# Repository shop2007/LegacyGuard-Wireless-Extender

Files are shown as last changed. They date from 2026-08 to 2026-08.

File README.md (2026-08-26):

# LegacyGuard Wireless Extender (Master to 4 Slave PIR/Sensors)

A wireless extension system to connect (via WiFi) up to 4 additional PIR sensors or N.O. contacts to a wired alarm control panel.  
Based on a **Master-Slave** architecture over a local Wi-Fi network, it allows a central board (Master) to monitor the status of up to 4 peripheral nodes (Slaves, wired locally to PIR sensors and powered locally) and activate a relay in case an alarm is detected.  
It is useful for adding PIR sensors to older-generation wired alarm systems without the need for additional cabling.

---

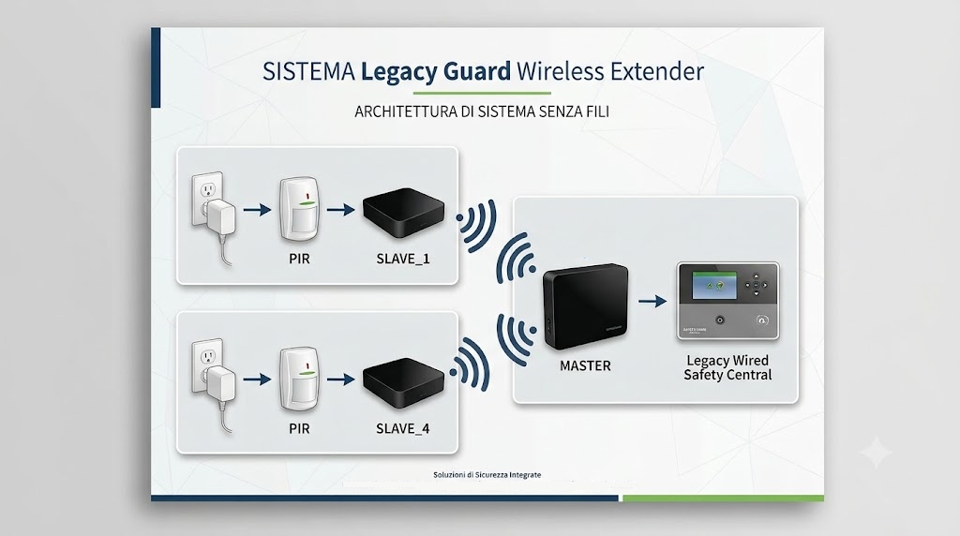
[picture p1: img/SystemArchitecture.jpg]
System Architecture
  
---

## 📐 System Architecture

```text
               +----------------------------------+
               |        MASTER (ESP32)            |
               |       IP: 192.168.4.1            |
               |   Relay Output / OLED Display    |
               +-----------------+----------------+
                                 |
         +-----------------------+-----------------------+
         | (Wi-Fi 802.11b - Network 192.168.4.x / Port 4210) |
         v                                               v
+------------------+                           +------------------+
| SLAVE 2 (ESP8266)|                           | SLAVE 3..5       |
| PIR Sensor       |  ... (up to 4 slaves) ... | (ESP8266)        |
| IP: 192.168.4.2  |                           | IP: 192.168.4.x  |
+------------------+                           +------------------+
```

link
- [master board ](https://github.com/shop2007/LegacyGuard-Wireless-Extender/tree/main/master-board)

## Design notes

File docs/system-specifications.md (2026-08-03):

# Specifiche Generali di Sistema — LegacyGuard Wireless Extender 

Questo documento descrive nel dettaglio l'architettura, le componenti, i protocolli di comunicazione e le modalità operative del sistema di allarme/ripetitore PIR Master-Slave.

---
System Architecture 
---

## 1. Architettura di Rete e Comunicazione

* **Tipologia Rete**: Wi-Fi Standard 802.11b (configurato per massimizzare la portata e la stabilità del segnale senza sleep radio).
* **Topologia**: Stella (Master al centro, Slave periferici).
* **Indirizzamento IP**:
  * **Master**: `192.168.4.1`
  * **Slave ID 2**: `192.168.4.2`
  * **Slave ID 3**: `192.168.4.3`
  * **Slave ID 4**: `192.168.4.4`
  * **Slave ID 5**: `192.168.4.5`
* **Porta del Server TCP Slave**: `80` (utilizzata dal Master per interrogare lo stato degli slave).
* **Potenza di Trasmissione TX (Slave)**: 20.5 dBm.

---

## 2. Modulo Master (`4MASTER32_displ_pir_wdog_100`)

Il nodo Master (basato su ESP32) coordina la rete, interroga periodicamente gli slave e gestisce la logica degli allarmi.

### 2.1 Logica di Allarme e Relè
* **Stati rilevati dallo Slave**:
  * `STA100`: Slave presente, nessun allarme.
  * `STA113`: Slave presente, allarme rilevato (sensore PIR attivato).
* **Comportamento Relè**: Se almeno uno slave risponde con `STA113`, l'uscita a relè viene attivata. Il relè resta eccitato per un tempo minimo di **2 secondi**, anche se la condizione di allarme rientra prima.
* **Mappatura Conservativa**: Un nodo visto anche solo una volta viene memorizzato come "Presente". Per essere dichiarato "Assente", deve fallire multiple risposte consecutive al polling.

### 2.2 Display OLED Master
La matrice del display mostra lo stato dei 4 nodi in forma sintetica:
* `A2`: Slave 2 in Allarme.
* `N3`: Slave 3 Normale / Senza allarme.
* `..`: Slave Non rilevato / Assente.

### 2.3 Indicatori LED Master
* **LED di Bordo**: Alterna stato ad ogni ciclo completo di polling (indicatore di attività).
* **LED Ausiliario (GPIO 9)**: Si illumina durante le fasi di scan e mappatura degli slave.

### 2.4 Ingressi di Servizio (Ponticelli Master)
* **GPIO 4 ➔ GND**: Salta il ritardo di riscaldamento iniziale di 90 secondi.
* **GPIO 10 ➔ GND**: Forza la rimappatura dinamica degli slave ad ogni ciclo.

### 2.5 Console Diagnostica (Seriale & Telnet)
L'accesso alla console di amministrazione avviene tramite **Seriale USB (115200 baud)** oppure via **Telnet**:
* **Accesso Telnet**: `telnet 192.168.4.1 2323`
* **Credenziali Console**: User: `admin` | Password: `Pautax2006`
* **Menu Diagnostico (Comando `m` o `M`)**:
  * `0`: Reset hardware della scheda.
  * `1`: Stampa il nome del file sorgente firmware.
  * `2`: Stampa statistiche dettagliate (allarmi, chiamate OK, chiamate FALLITE per ogni slave).
  * `3`: Abilita/Disabilita diagnostica estesa (tracing funzioni).
  * `4`: Avvia scan continuo di presenza/assenza (uscita con `q`).
  * `5`: Attiva la modalità aggiornamento OTA via Web.
  * `6`: Stampa Indirizzo MAC.
  * `99`: Uscita dal menu.

### 2.6 Aggiornamento Firmware Web OTA
1. Aprire la sessione Telnet ed entrare nel menu diagnostico (`m`).
2. Selezionare l'opzione `5` per abilitare l'OTA (il Master entra in modalità manutenzione).
3. Aprire il browser all'indirizzo `http://192.168.4.1/update` (HTTP, non HTTPS).
4. Inserire le credenziali OTA (`admin` / `Pautax2006`).
5. Caricare il file `.bin` compilato e attendere il riavvio automatico.

---

## 3. Modulo Slave PIR (`Wemos D1 mini`)

Ogni nodo Slave acquisisce il segnale dal sensore PIR e risponde alle chiamate TCP del Master.

### 3.1 Funzionalità Principali
* **Rilevamento Allarme Memorizzato (Latch)**: Quando il PIR rileva un'intrusione, il flag di allarme viene alzato e memorizzato (latched). **Importante**: il semplice polling da parte del Master NON azzera lo stato di allarme.
* **Reset Allarme via Comando `STA155`**: Lo stato di allarme memorizzato (e il relativo LED diagnostico) si azzera **esclusivamente** quando lo Slave riceve il comando specifico con codice `155` / `STA155` (inviato via TCP o Seriale).
* **Watchdog Software**: Timer a 8 secondi con auto-reset della scheda in caso di blocco del codice.
* **Risposta TCP**: Invia lo stato (`STA100` in assenza di allarme, `STA113` in presenza di allarme latched), il numero progressivo di chiamata (`CALL`) e la potenza del segnale Wi-Fi (`RADIO` / `RSSI`).

### 3.2 Display OLED Slave
* **Riga 1**: ID Slave (`SLAVE_ID`) e stato connessione Wi-Fi (`CONN` / `NOCN`).
* **Riga 2**: Stato Allarme (`OK` / `AL`).
* *Fase di avvio*: Mostra il countdown dei secondi rimanenti al riscaldamento del sensore PIR.

### 3.3 Codici e Funzionalità LED Slave
* **LED_BUILTIN** (attivo LOW):
  * **Toggle (1 “blink” di stato)**: Inverte il proprio stato ad ogni risposta trasmessa al Master (sia via TCP sia via comando seriale `?`). Serve da indicatore di attività/polling.
  * **Doppio blink (2 blink) durante riscaldamento PIR**: Nella fase di countdown di 90 s (se non saltata tramite D6→GND) esegue una sequenza fissa di **2 lampeggi rapidi** per ogni secondo di attesa:
    * ON 120 ms → OFF 120 ms → ON 120 ms → ripristino stato precedente + pausa 640 ms.
    * La sequenza è ripetuta per ogni secondo del countdown (funzione `blinkWarmupDouble()`).
  * Non sono implementati pattern a 3 o 4 blink; il LED_BUILTIN usa esclusivamente il toggle di attività e il doppio blink di warmup.
* **LED Diagnostico Allarme (`LED_DIAG_PIN` su D7)**:
  * **Si accende (HIGH)**: Non appena il PIR rileva un allarme e alza il flag interno.
  * **Rimane ACCESO**: Anche durante i normali cicli di polling/interrogazione, finché l'allarme resta memorizzato.
  * **Si spegne (LOW)**: Soltanto dopo la ricezione esplicita del comando di reset (inviata dal MASTER) `STA155`.

### 3.4 Ingressi Hardware e Interfacce Slave
* **Pin D6 (`SkipDelayPir`)**: Pull-up interno. Se ponticellato a GND all'avvio, salta il countdown di 90s del PIR (utilizzato per debug/test).
* **Pin D5 (`InputPir`)**: Ingresso del sensore PIR con pull-up interno. Supporta la configurazione con optocoppiatore/contatto normalmente chiuso (`PirReverse = false` o `true` in base alla logica del sensore).
* **Pin D7 (`LED_DIAG_PIN`)**: Uscita attiva alta collegata all'anodo del LED diagnostico allarme (con opportuna resistenza di limitazione verso GND).
* **Interfaccia Seriale USB**:
  * Inviando `?` simula una chiamata di polling fornendo la risposta di stato.
  * Inviando `155` o `STA155` forza il reset immediato dell'allarme latched e lo spegnimento del LED diagnostico.

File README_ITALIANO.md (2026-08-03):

#  LegacyGuard Wireless Extender (Master to 4 Slave PIR/Sensors)

Un sistema di estensione wireless per collegare (WiFi) ulteriori 4 sensori PIR oppure contatti n.o., ad una centrale cablata. 
Basato su architettura **Master-Slave** , tramite una rete Wi-Fi locale, consente ad una scheda centrale (Master) di monitorare lo stato di fino a 4 nodi periferici (Slave cablati localmente con sensori PIR ed alimentati localmente) e attivare un relè in caso di allarme rilevato.
E' utile per aggiungere sensori PIR a sistemi di allarme cablati di vecchia generazione, senza dover aggiungere 
cablaggi. 

---

System Architecture 
---

## 📐 Architettura del Sistema

```text
               +----------------------------------+
               |        MASTER (ESP32)            |
               |       IP: 192.168.4.1            |
               |   Uscita Relè / Display OLED     |
               +-----------------+----------------+
                                 |
         +-----------------------+-----------------------+
         | (Wi-Fi 802.11b - Rete 192.168.4.x / Port 4210) |
         v                                               v
+------------------+                           +------------------+
| SLAVE 2 (ESP8266)|                           | SLAVE 3..5       |
| Sensor PIR       |  ... (fino a 4 slave) ... | (ESP8266)        |
| IP: 192.168.4.2  |                           | IP: 192.168.4.x  |
+------------------+                           +------------------+

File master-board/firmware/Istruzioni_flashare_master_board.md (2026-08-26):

**Passi consigliati per chi parte da zero:**
**Programmazione scheda MASTER:**
Aprire il file - <https://github.com/shop2007/LegacyGuard-Wireless-Extender/tree/main/master-board%2Fdocs> ed andare al punto 8 toolchain (Riprodurre il progetto: cosa serve) 

---

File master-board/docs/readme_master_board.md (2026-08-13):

# General System Specifications — LegacyGuard Wireless Extender

This document describes in detail the architecture, components, communication protocols, and operating modes of the wireless link system for a legacy (wired) alarm control panel.

---

## 1. Network Architecture and Communication

* **Network Type**: Wi-Fi Standard 802.11b (configured to maximize range and signal stability without radio sleep).
* **Topology**: Star (Master at the center, peripheral Slaves).
* **IP Addressing**:
  * **Master**: `192.168.4.1`
  * **Slave ID 2**: `192.168.4.2`
  * **Slave ID 3**: `192.168.4.3`
  * **Slave ID 4**: `192.168.4.4`
  * **Slave ID 5**: `192.168.4.5`
* **Slave TCP Server Port**: `80` (used by the Master to query the status of the slaves).
* **TX Transmission Power (Slave)**: 20.5 dBm.

---

## 2. Master Module (`4MASTER32_displ_pir_wdog_70`)

The Master node (based on ESP32) coordinates the network, periodically queries the slaves, and manages the alarm logic.

### 2.1 Alarm Logic and Relay
* **States detected by the Slave**:
  * `STA100`: Slave present, no alarm.
  * `STA113`: Slave present, alarm detected (PIR sensor activated).
* **Relay Behavior**: If at least one slave responds with `STA113`, the relay output is activated. The relay remains energized for a minimum time of **2 seconds**, even if the alarm condition clears earlier.
* **Conservative Mapping**: A node seen even only once is memorized as "Present". To be declared "Absent", it must fail multiple consecutive responses to polling.

### 2.2 Master OLED Display
The display matrix shows the status of the 4 nodes in synthetic form:
* `A2`: Slave 2 in Alarm.
* `N3`: Slave 3 Normal / No alarm.
* `..`: Slave Not detected / Absent.

### 2.3 Master LED Indicators
* **Edge LED**: Alternates state at each complete polling cycle (activity indicator).
* **Auxiliary LED (GPIO 9)**: Lights up during slave scan and mapping phases.

### 2.4 Service Inputs (Master Jumpers)
* **GPIO 4 ➔ GND**: Skips the initial 90-second warm-up delay.
* **GPIO 10 ➔ GND**: Forces dynamic remapping of the slaves at every cycle.

### 2.5 Diagnostic Console (Serial & Telnet)
Access to the administration console is via **USB Serial (115200 baud)** or via **Telnet**:
* **Telnet Access**: `telnet 192.168.4.1 2323`
* **Console Credentials**: User: `admin` | Password: `Pautax2006`
* **Diagnostic Menu (Command `m` or `M`)**:
  * `0`: Hardware reset of the board.
  * `1`: Prints the source firmware file name.
  * `2`: Prints detailed statistics (alarms, OK calls, FAILED calls for each slave).
  * `3`: Enables/Disables extended diagnostics (function tracing).
  * `4`: Starts continuous presence/absence scan (exit with `q`).
  * `5`: Activates Web OTA update mode.
  * `6`: Prints MAC Address.
  * `99`: Exit from the menu.

### 2.6 Web OTA Firmware Update
1. Open the Telnet session and enter the diagnostic menu (`m`).
2. Select option `5` to enable OTA (the Master enters maintenance mode).
3. Open the browser at the address `http://192.168.4.1/update` (HTTP, not HTTPS).
4. Enter the OTA credentials (`admin` / `Pautax2006`).
5. Upload the compiled `.bin` file and wait for the automatic reboot.
p.s. more details on programming and OTA are available in paragraph 8. (Reproducing the project: what is needed)

---

## 3. Slave PIR Module (`ESP8266 / Wemos D1 mini`)

Each Slave node acquires the signal from the PIR sensor and responds to TCP calls from the Master.

### 3.1 Main Functionalities
* **Latched Alarm Detection**: When the PIR detects an intrusion, the alarm flag is raised and latched. **Important**: simple polling by the Master does NOT clear the alarm state.
* **Alarm Reset via Command `STA155`**: The latched alarm state (and the related diagnostic LED) is cleared **exclusively** when the Slave receives the specific command with code `155` / `STA155` (sent via TCP or Serial).
* **Software Watchdog**: 8-second timer with automatic board reset in case of code freeze.
* **TCP Response**: Sends the status (`STA100` in the absence of alarm, `STA113` in the presence of latched alarm), the progressive call number (`CALL`), and the Wi-Fi signal strength (`RADIO` / `RSSI`).

### 3.2 Slave OLED Display
* **Line 1**: Slave ID (`SLAVE_ID`) and Wi-Fi connection status (`CONN` / `NOCN`).
* **Line 2**: Alarm status (`OK` / `AL`).
* *Startup phase*: Shows the countdown of remaining seconds for PIR sensor warm-up.

### 3.3 Slave LED Codes and Functionalities
* **LED_BUILTIN** (active LOW):
  * **Toggle (1 “status blink”)**: Inverts its state at every response transmitted to the Master (both via TCP and via serial command `?`). Serves as an activity/polling indicator.
  * **Double blink (2 blinks) during PIR warm-up**: In the 90 s countdown phase (if not skipped via D6→GND) it performs a fixed sequence of **2 rapid flashes** for each second of waiting:
    * ON 120 ms → OFF 120 ms → ON 120 ms → restore previous state + 640 ms pause.
    * The sequence is repeated for each second of the countdown (function `blinkWarmupDouble()`).
  * Patterns with 3 or 4 blinks are not implemented; the LED_BUILTIN uses exclusively the activity toggle and the warm-up double blink.
* **Alarm Diagnostic LED (`LED_DIAG_PIN` on D7)**:
  * **Turns on (HIGH)**: As soon as the PIR detects an alarm and raises the internal flag.
  * **Remains ON**: Even during normal polling/interrogation cycles, as long as the alarm remains latched.
  * **Turns off (LOW)**: Only after explicit reception of the reset command (sent by the MASTER) `STA155`.

### 3.4 Slave Hardware Inputs and Interfaces
* **Pin D6 (`SkipDelayPir`)**: Internal pull-up. If jumpered to GND at startup, skips the 90 s PIR countdown (used for debug/test).
* **Pin D5 (`InputPir`)**: PIR sensor input with internal pull-up. Supports configuration with optocoupler/normally closed contact (`PirReverse = false` or `true` depending on the sensor logic).
* **Pin D7 (`LED_DIAG_PIN`)**: Active-high output connected to the anode of the alarm diagnostic LED (with appropriate current-limiting resistor to GND).
* **USB Serial Interface**:
  * Sending `?` simulates a polling call providing the status response.
  * Sending `155` or `STA155` forces the immediate reset of the latched alarm and turns off the diagnostic LED.

# LegacyGuard Wireless Extender

**Network Master board for monitoring 4 slave boards connected to PIR-type sensors, Dual technology, normally closed magnetic switches.**

The **master** board, based on **ESP32-C3**, manages a proprietary local WiFi network (Access Point) consisting of one master and up to **4 remote slaves** (expandable to 8 with firmware modification). The master periodically queries the slaves, acquires their operational status (presence / alarm), and drives a relay output in case of alarm. The status of the 4 slaves is shown in real time on an OLED display.

> This document describes the hardware, protocol, firmware, and the procedure to reproduce or modify the project.

---

## 1. Overview

| | |
|---|---|
| **MCU** | ESP32-C3 (API core: `WiFi.h`, `WebServer.h`, `esp_task_wdt.h`, `Update.h`) |
| **Role** | Network Master: polling of up to 4 slaves, alarm management, display, OTA |
| **Network** | Own WiFi Access Point (no need for the WiFi router to be on) |
| **Output** | Alarm relay, OLED display, 2 status LEDs |
| **Update** | OTA via web interface, protected by authentication |
| **Diagnostics** | Serial console (115200 baud) or Telnet, with command menu |

---

## 2. Network Architecture

- The master creates its own **WiFi Access Point** (SoftAP), to which slaves and the diagnostic station connect.
- Internally managed network on a static range (fixed master IP: `192.168.4.1`).
- Each slave has an ID (`SLAVE_ID`) ranging, according to the project numbering, from 2 to 5 (the master has fixed ID 1, so that master and slaves do not collide on the same network).
- Each slave, when queried, transmits to the master a synthetic status derived from an internal code:
  - status (display) **A** (alarm) ↔ real code `STA113`
  - status (display) **N** (normal) ↔ real code `STA100`
  - status (display) **..** ↔ slave absent / not detected

---

## 3. Master Operating Logic

- The master cyclically queries (polls) all configured slaves.
- **If at least one slave is in alarm**, the output relay is activated.
- **Minimum hysteresis**: once activated, the relay remains active for **at least 2 seconds**, even if the alarm clears earlier.
- **Slave presence detection (conservative mapping)**, designed for non-optimal radio networks (distance, weak signal):
  - in the mapping phase, a slave seen even only once is considered present;
  - in normal polling, a slave is declared absent only after **multiple consecutive missed responses** (not on the first one).

---

## 4. User Interface on the Board

### 4.1 OLED Display
Shows the status of the 4 slaves in compact form, two characters per slave:

| Code | Meaning |
|---|---|
| `A2` | slave 2 in alarm |
| `N3` | slave 3 present, no alarm |
| `..` | slave not present / not detected |

### 4.2 LEDs
- **Edge LED (built-in)**: normal master operation, changes state at every complete polling cycle (useful to verify "at a glance" that the firmware is not frozen).
- **Auxiliary LED (GPIO 9)**: on during slave mapping/scan, off at the end of the operation.

### 4.3 Service Jumpers (jumper to GND)
| ESP32-C3 CHIP Pin | Function |
|---|---|
| GPIO 4 → GND | skips the initial startup delay (90 s) |
| GPIO 10 → GND | forces complete remapping of the slaves at every cycle, for debug only |

---

## 5. Diagnostic Access

The master exposes a diagnostic console reachable in two ways:

- **USB Serial**, 115200 baud
- **Telnet**, on the master's WiFi network, default port `2323`

Typical connection command to launch from console (CMD window):
```
telnet 192.168.4.1 2323
```

Access requires console username/password. To open the diagnostic menu, from the session (serial or Telnet) send the character **`m`**.

### Diagnostic Menu — Available Commands

| Command | Function |
|---|---|
| `0` | Hardware reset of the board |
| `1` | Displays the source file name of the running firmware |
| `2` | Statistics per slave: number of alarms, OK readings, failed readings (`ALRM`, `OK`, `NON_OK`) useful for evaluating the quality of the WiFi connection over the long term |
| `3` | Enables/disables extended diagnostics (detailed function entry/exit tracing for the developer) |
| `4` | Continuous scan of present/absent slaves (ends with `q`) |
| `5` | Enables/disables web OTA mode |
| `6` | Prints the board MAC address |
| `99` | Exits the menu |

Example output of command `2`: (n. alarms, presence readings on network ok, presence readings on network failed)
```
Slave2 ALRM=3 OK=6403 NON_OK=2
Slave3 ALRM=0 OK=0    NON_OK=6405
Slave4 ALRM=0 OK=0    NON_OK=6405
Slave5 ALRM=0 OK=0    NON_OK=6405
```

---

## 6. Firmware Update via OTA

The firmware includes an OTA web server (`WebServer` + `Update.h` library) always available on the master's IP, protected by HTTP Basic authentication.

**Complete procedure:**
1. Download the updated (`.bin`) file.
2. Save it in a known folder.
3. Disconnect the PC from the router network and connect it to the WiFi network `88888888` pass `88888888`.
4. Open a Telnet session to `192.168.4.1:2323`. (From CMD prompt write "telnet 192.168.4.1 2323")
5. Authenticate with user 'admin' and password Pautax2006.
6. Send `m` to open the diagnostic menu.
7. Send `5` to activate OTA mode.   ??????? verify procedure
8. Open in the browser `http://192.168.4.1/update` (**http**, not https).
9. Enter the OTA credentials (username admin, password Pautax2006).
10. On the web page with browse, search on disk for the `.bin` file.
11. Wait for the upload to complete.
12. Wait for the automatic reboot of the board.
13. Verify the correct operation of the new firmware.

During OTA the master enters **maintenance mode** (polling/normal functions are suspended).

---

## 7. Firmware Structure and Project Files

```
4MASTER32/
├── 4MASTER32_startup_03_88888888.ino      # first boot / recovery sketch (OTA + serial)
├── 4MASTER32_displ_pir_wdog_100.ino.bin   # actual firmware  
```

### 7.1 First Boot Sketch (`4MASTER32_startup_02_88888888.ino`)
The *startup* sketch is a **minimal first boot / recovery variant**: it only mounts the WiFi Access Point, the OTA web server, and the hardware watchdog, periodically printing on the serial a message inviting to update the firmware. **It does not contain** the slave polling logic, display, and relay described in the manual: it is designed to easily flash a "virgin" board (or recover a locked board) and bring it via OTA to the complete application firmware, without having to reconnect it via USB.

Main technical elements:
- Hardware task watchdog (`esp_task_wdt`), 8 s timeout, with `trigger_panic` active — if the loop freezes, the board resets itself.
- OTA web server (`WebServer` on port 80) with HTTP Basic authentication.
- `/update` endpoint for binary upload, handled in streaming (`UPLOAD_FILE_START` / `WRITE` / `END` / `ABORTED`) with progress log on serial.
- Automatic reboot (`ESP.restart()`) 1.5 s after OTA completion.

### 7.2 `Master_ID.h`
Defines the master's identity on the network and the network/console parameters:
- `MASTER_ID` — fixed at `1` (slaves use 2–9, max 8 slaves on the network).
- SSID / password of the master's Access Point.
- Static IP, gateway, subnet of the AP.
- Application TCP port, Telnet diagnostic console port and password.
- OTA web server port, user, and password.
- `NUM_SLAVES`, `FIRST_SLAVE_ID` — number and first ID of the expected slaves on the network.
- An empirical reminder on radio signal level measurements (e.g. at 30 cm about −33 dB, at 7 m about −85/−92 dB), useful to understand the AP range limits during system design.

PLEASE NOTE: this file is not accessible, but contained in the .bin file.

### 7.3 `Choice of WiFi SSID and PASSWORD Parameters`
- The desired local network name (SSID) and WiFi password must be requested at the address register@realmeteo.com, together with the MAC Address of the ESP32-C3 board, readable from the service menu with command 6.
- These parameters (SSID and PASSWORD) must be reported identically in the Slave_ID.h file before programming the SLAVE modules (WEMOS LOLIN D1), by editing these two lines
- const char* WIFI_SSID = "DESIRED-WIFI-NETWORK-NAME";
- const char* WIFI_PASS = "WIFI-PASSWORD";

### 7.4 `Technical Note: partitions.csv`
ESP32-c3 flash partitioning table, **OTA dual-app** scheme (necessary for safe OTA updates, with rollback):

| Name | Type | Sub-type | Offset | Size |
|---|---|---|---|---|
| `nvs` | data | nvs | `0x9000` | 20 KB |
| `otadata` | data | ota | `0xe000` | 8 KB |
| `app0` | app | ota_0 | `0x10000` | 1900 KB |
| `app1` | app | ota_1 | — | 1900 KB |
| `coredump` | data | coredump | — | 128 KB |

Two application slots (`app0`/`app1`) of 1900 KB each allow the OTA to write the new firmware to the inactive slot and switch to it only after a successful upload, maintaining the possibility of returning to the previous firmware in case of problems. The `coredump` partition stores a dump in case of crash to facilitate debugging.

---

## 8. Reproducing the Project: What is Needed

**Hardware:**
- ESP32‐C3 board with 0.42-inch OLED display WiFi Bluetooth
- PCB
- Relay
- PIR sensors and dedicated D1 slave boards (one for each point to monitor)
- 2 LEDs (edge + auxiliary on GPIO 9)
- 2 jumpers/buttons to GND on GPIO 4 and GPIO 10

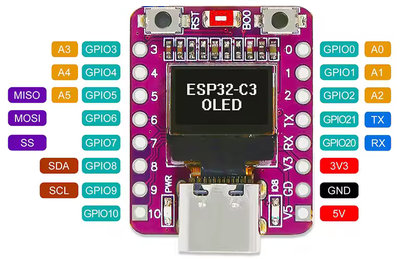
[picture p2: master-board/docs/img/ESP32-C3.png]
ESP32-C3


**Toolchain:**
- Arduino IDE with ESP32 core installed and setting of the file "http://arduino.esp8266.com/stable/package_esp8266com_index.json" in preferences
- Libraries: `WiFi.h`, `WebServer.h`, `Update.h`, `esp_task_wdt.h` (included in the ESP32 core, no additional installation required)

**MASTER Board Programming:**
0. Download all the files present in the firmware folder, copying them to a known folder on your PC.
0.1 Optional but preferable: Remove the ESP32-C3 board from the board and connect it to the PC via the USB cable
1. In Arduino IDE2, set the following:
1.1 File->Preferences-> Additional board manager url-> http://arduino.esp8266.com/stable/package_esp8266com_index.json
1.2 Board "ESP32‐C3 Dev Module"
1.3 Tools-> Erase all flash before upload ->Enabled
1.4 Tools-> USB CDC on boot -> Enabled
2. Open the sketch "4MASTER32_startup_02_88888888.ino" and upload it to an ESP32C3 board (preferably with 0.42-inch OLED display).
2.1 Verify from the serial terminal at 115200 baud the following message:  =========================================
SoftAP started - SSID: 88888888
IP for OTA update: http://192.168.4.1
=========================================
perform OTA update

3. Verify with the PC that among the other WiFi networks there is also the network with SSID = **88888888** (it reads INTERNET NOT AVAILABLE).
4. Disconnect the PC from your router's WiFi network and connect to the network with SSID 88888888 using password 88888888
5. In the PC browser type the following address (optionally leave the serial monitor active) http://192.168.4.1/update   (attention, not https)
5.1 You will be asked to authenticate: user 'admin' password 'Pautax2006'
6. With browse search for the file 4MASTER32_displ_pir_wdog_100.bin (N.B. 100 is the version, you might also find an upgrade with another number).
6.1 Program the board with the 'Upload Firmware' button
6.2 on the serial terminal you read:
OTA: Firmware upload started.
OTA: File = 4MASTER32_displ_pir_wdog_100.ino.bin
OTA: Upload completed. Bytes received: 1072240
OTA: update completed. Restarting...
perform OTA update
Device restart in progress...
6.3 on the browser you read: **Update completed. The master is restarting.**

---

## 9. PCB

- The PCBs for mounting MASTER and SLAVE boards are under development and will be distributed at `cost price`, if you are interested book them.

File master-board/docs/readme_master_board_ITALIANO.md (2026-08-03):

# Specifiche Generali di Sistema — LegacyGuard Wireless Extender 

Questo documento descrive nel dettaglio l'architettura, le componenti, i protocolli di comunicazione e le modalità operative del sistema di collegamento wireless per una centrale antifurto legacy (wired)

---

## 1. Architettura di Rete e Comunicazione[cite: 2]

* **Tipologia Rete**: Wi-Fi Standard 802.11b (configurato per massimizzare la portata e la stabilità del segnale senza sleep radio).[cite: 2]
* **Topologia**: Stella (Master al centro, Slave periferici).[cite: 2]
* **Indirizzamento IP**:[cite: 2]
  * **Master**: `192.168.4.1`[cite: 2]
  * **Slave ID 2**: `192.168.4.2`[cite: 2]
  * **Slave ID 3**: `192.168.4.3`[cite: 2]
  * **Slave ID 4**: `192.168.4.4`[cite: 2]
  * **Slave ID 5**: `192.168.4.5`[cite: 2]
* **Porta del Server TCP Slave**: `80` (utilizzata dal Master per interrogare lo stato degli slave).[cite: 1, 2]
* **Potenza di Trasmissione TX (Slave)**: 20.5 dBm.[cite: 2]

---

## 2. Modulo Master (`4MASTER32_displ_pir_wdog_70`)[cite: 2]

Il nodo Master (basato su ESP32) coordina la rete, interroga periodicamente gli slave e gestisce la logica degli allarmi.[cite: 2]

### 2.1 Logica di Allarme e Relè[cite: 2]
* **Stati rilevati dallo Slave**:[cite: 2]
  * `STA100`: Slave presente, nessun allarme.[cite: 2]
  * `STA113`: Slave presente, allarme rilevato (sensore PIR attivato).[cite: 2]
* **Comportamento Relè**: Se almeno uno slave risponde con `STA113`, l'uscita a relè viene attivata. Il relè resta eccitato per un tempo minimo di **2 secondi**, anche se la condizione di allarme rientra prima.[cite: 2]
* **Mappatura Conservativa**: Un nodo visto anche solo una volta viene memorizzato come "Presente". Per essere dichiarato "Assente", deve fallire multiple risposte consecutive al polling.[cite: 2]

### 2.2 Display OLED Master[cite: 2]
La matrice del display mostra lo stato dei 4 nodi in forma sintetica:[cite: 2]
* `A2`: Slave 2 in Allarme.[cite: 2]
* `N3`: Slave 3 Normale / Senza allarme.[cite: 2]
* `..`: Slave Non rilevato / Assente.[cite: 2]

### 2.3 Indicatori LED Master[cite: 2]
* **LED di Bordo**: Alterna stato ad ogni ciclo completo di polling (indicatore di attività).[cite: 2]
* **LED Ausiliario (GPIO 9)**: Si illumina durante le fasi di scan e mappatura degli slave.[cite: 2]

### 2.4 Ingressi di Servizio (Ponticelli Master)[cite: 2]
* **GPIO 4 ➔ GND**: Salta il ritardo di riscaldamento iniziale di 90 secondi.[cite: 2]
* **GPIO 10 ➔ GND**: Forza la rimappatura dinamica degli slave ad ogni ciclo.[cite: 2]

### 2.5 Console Diagnostica (Seriale & Telnet)[cite: 2]
L'accesso alla console di amministrazione avviene tramite **Seriale USB (115200 baud)** oppure via **Telnet**:[cite: 2]
* **Accesso Telnet**: `telnet 192.168.4.1 2323`[cite: 2]
* **Credenziali Console**: User: `admin` | Password: `Pautax2006`[cite: 2]
* **Menu Diagnostico (Comando `m` o `M`)**:[cite: 2]
  * `0`: Reset hardware della scheda.[cite: 2]
  * `1`: Stampa il nome del file sorgente firmware.[cite: 2]
  * `2`: Stampa statistiche dettagliate (allarmi, chiamate OK, chiamate FALLITE per ogni slave).[cite: 2]
  * `3`: Abilita/Disabilita diagnostica estesa (tracing funzioni).[cite: 2]
  * `4`: Avvia scan continuo di presenza/assenza (uscita con `q`).[cite: 2]
  * `5`: Attiva la modalità aggiornamento OTA via Web.[cite: 2]
  * `6`: Stampa Indirizzo MAC.[cite: 2]
  * `99`: Uscita dal menu.[cite: 2]

### 2.6 Aggiornamento Firmware Web OTA[cite: 2]
1. Aprire la sessione Telnet ed entrare nel menu diagnostico (`m`).[cite: 2]
2. Selezionare l'opzione `5` per abilitare l'OTA (il Master entra in modalità manutenzione).[cite: 2]
3. Aprire il browser all'indirizzo `http://192.168.4.1/update` (HTTP, non HTTPS).[cite: 2]
4. Inserire le credenziali OTA (`admin` / `Pautax2006`).[cite: 2]
5. Caricare il file `.bin` compilato e attendere il riavvio automatico.[cite: 2]
p.s. maggiori dettagli sulla programmazione e OTA sono disponibili al paragrafo 8. (Riprodurre il progetto: cosa serve)
---

## 3. Modulo Slave PIR (`ESP8266 / Wemos D1 mini`)[cite: 1, 2]

Ogni nodo Slave acquisisce il segnale dal sensore PIR e risponde alle chiamate TCP del Master.[cite: 2]

### 3.1 Funzionalità Principali[cite: 2]
* **Rilevamento Allarme Memorizzato (Latch)**: Quando il PIR rileva un'intrusione, il flag di allarme viene alzato e memorizzato (latched)[cite: 1]. **Importante**: il semplice polling da parte del Master NON azzera lo stato di allarme[cite: 1].
* **Reset Allarme via Comando `STA155`**: Lo stato di allarme memorizzato (e il relativo LED diagnostico) si azzera **esclusivamente** quando lo Slave riceve il comando specifico con codice `155` / `STA155` (inviato via TCP o Seriale)[cite: 1].
* **Watchdog Software**: Timer a 8 secondi con auto-reset della scheda in caso di blocco del codice[cite: 2].
* **Risposta TCP**: Invia lo stato (`STA100` in assenza di allarme, `STA113` in presenza di allarme latched), il numero progressivo di chiamata (`CALL`) e la potenza del segnale Wi-Fi (`RADIO` / `RSSI`)[cite: 1, 2].

### 3.2 Display OLED Slave[cite: 2]
* **Riga 1**: ID Slave (`SLAVE_ID`) e stato connessione Wi-Fi (`CONN` / `NOCN`)[cite: 2].
* **Riga 2**: Stato Allarme (`OK` / `AL`)[cite: 2].
* *Fase di avvio*: Mostra il countdown dei secondi rimanenti al riscaldamento del sensore PIR[cite: 2].

### 3.3 Codici e Funzionalità LED Slave[cite: 1, 2]
* **LED_BUILTIN** (attivo LOW):
  * **Toggle (1 “blink” di stato)**: Inverte il proprio stato ad ogni risposta trasmessa al Master (sia via TCP sia via comando seriale `?`). Serve da indicatore di attività/polling.
  * **Doppio blink (2 blink) durante riscaldamento PIR**: Nella fase di countdown di 90 s (se non saltata tramite D6→GND) esegue una sequenza fissa di **2 lampeggi rapidi** per ogni secondo di attesa:
    * ON 120 ms → OFF 120 ms → ON 120 ms → ripristino stato precedente + pausa 640 ms.
    * La sequenza è ripetuta per ogni secondo del countdown (funzione `blinkWarmupDouble()`).
  * Non sono implementati pattern a 3 o 4 blink; il LED_BUILTIN usa esclusivamente il toggle di attività e il doppio blink di warmup.
* **LED Diagnostico Allarme (`LED_DIAG_PIN` su D7)**:
  * **Si accende (HIGH)**: Non appena il PIR rileva un allarme e alza il flag interno[cite: 1].
  * **Rimane ACCESO**: Anche durante i normali cicli di polling/interrogazione, finché l'allarme resta memorizzato[cite: 1].
  * **Si spegne (LOW)**: Soltanto dopo la ricezione esplicita del comando di reset (inviata dal MASTER) `STA155`[cite: 1].

### 3.4 Ingressi Hardware e Interfacce Slave[cite: 1, 2]
* **Pin D6 (`SkipDelayPir`)**: Pull-up interno. Se ponticellato a GND all'avvio, salta il countdown di 90s del PIR (utilizzato per debug/test)[cite: 1, 2].
* **Pin D5 (`InputPir`)**: Ingresso del sensore PIR con pull-up interno. Supporta la configurazione con optocoppiatore/contatto normalmente chiuso (`PirReverse = false` o `true` in base alla logica del sensore)[cite: 1, 2].
* **Pin D7 (`LED_DIAG_PIN`)**: Uscita attiva alta collegata all'anodo del LED diagnostico allarme (con opportuna resistenza di limitazione verso GND)[cite: 1].
* **Interfaccia Seriale USB**:
  * Inviando `?` simula una chiamata di polling fornendo la risposta di stato[cite: 1].
  * Inviando `155` o `STA155` forza il reset immediato dell'allarme latched e lo spegnimento del LED diagnostico[cite: 1].# LegacyGuard Wireless Extender 

** Scheda Master di rete per monitoraggio 4 schede slave connesse a sensori tipo PIR, Doppia tecnologia, interruttori magnetici normalmente chiusi.**

La scheda **master**, basata su **ESP32-C3**, gestisce una rete locale WiFi proprietaria (Access Point) composta da un master e fino a **4 slave remoti** (espandibile a 8 con modifica firmware). Il master interroga periodicamente gli slave, ne acquisisce lo stato operativo (presenza / allarme) e pilota un'uscita a relè in caso di allarme. Lo stato dei 4 slave viene mostrato in tempo reale su un display OLED.

> Questo documento descrive l'hardware, il protocollo, il firmware e la procedura per riprodurre o modificare il progetto. 

---

## 1. Panoramica

| | |
|---|---|
| **MCU** | ESP32-C3 (API core: `WiFi.h`, `WebServer.h`, `esp_task_wdt.h`, `Update.h`) |
| **Ruolo** | Master di rete: polling di fino a 4 slave, gestione allarme, display, OTA |
| **Rete** | Access Point WiFi proprio (non serve avere il router WiFi acceso) |
| **Output** | Relè di allarme, display OLED, 2 LED di stato |
| **Aggiornamento** | OTA via interfaccia web, protetta da autenticazione |
| **Diagnostica** | Console seriale (115200 baud) o Telnet, con menu a comandi |

---

## 2. Architettura di rete

- Il master crea un proprio **Access Point WiFi** (SoftAP), a cui slave e postazione di diagnostica si collegano.
- Rete gestita internamente su un range statico (IP master fisso: `192.168.4.1`).
- Ogni slave ha un ID (`SLAVE_ID`) compreso, secondo la numerazione del progetto, tra 2 e 5 (il master ha ID 1, fisso, così master e slave non collidono sulla stessa rete).
- Ogni slave, quando interrogato, trasmette al master uno stato sintetico ricavato da un codice interno:
  - stato (display) **A** (allarme) ↔ codice reale `STA113`
  - stato (display) **N** (normale) ↔ codice reale `STA100`
  - stato (display) **..** ↔ slave assente / non rilevato

---

## 3. Logica di funzionamento del master

- Il master interroga (poll) ciclicamente tutti gli slave configurati.
- **Se almeno uno slave risulta in allarme**, il relè di uscita si attiva.
- **Isteresi minima**: una volta attivato, il relè resta attivo per **almeno 2 secondi**, anche se l'allarme rientra prima.
- **Rilevamento presenza slave (mappatura conservativa)**, pensato per reti radio non ottimali (distanza, segnale debole):
  - in fase di mappatura, uno slave visto anche una sola volta viene considerato presente;
  - in polling normale, uno slave viene dichiarato assente solo dopo **più mancate risposte consecutive** (non alla prima).

---

## 4. Interfaccia utente sulla scheda

### 4.1 Display OLED
Mostra in forma compatta lo stato dei 4 slave, due caratteri per slave:

| Codice | Significato |
|---|---|
| `A2` | slave 2 in allarme |
| `N3` | slave 3 presente, nessun allarme |
| `..` | slave non presente / non rilevato |

### 4.2 LED
- **LED di bordo (built-in)**: normale funzionamento del master, cambia stato a ogni ciclo completo di polling (utile per verificare "a colpo d'occhio" che il firmware non sia bloccato).
- **LED ausiliario (GPIO 9)**: acceso durante la mappatura/scan degli slave, spento a fine operazione.

### 4.3 Ponticelli di servizio (jumper verso GND)
| Pin  CHIP ESP32 C3  | Funzione |
|---|---|
| GPIO 4 → GND | salta il ritardo iniziale di avvio (90 s) |
| GPIO 10 → GND | forza la rimappatura completa degli slave a ogni ciclo, solo per debug |

---

## 5. Accesso diagnostico

Il master espone una console diagnostica raggiungibile in due modi:

- **Seriale USB**, 115200 baud
- **Telnet**, sulla rete WiFi del master, porta di default `2323`

Comando di connessione tipico da lanciare da console (finestra CMD):
```
telnet 192.168.4.1 2323
```

L'accesso richiede username/password di console. Per aprire il menu diagnostico, dalla sessione (seriale o Telnet) inviare il carattere **`m`** .

### Menu diagnostico — comandi disponibili

| Comando | Funzione |
|---|---|
| `0` | Reset hardware della scheda |
| `1` | Visualizza nome file sorgente del firmware in esecuzione |
| `2` | Statistiche per slave: n° allarmi, letture OK, letture fallite (`ALRM`, `OK`, `NON_OK`) utile per valutare la bontà della connessione WiFi a lungo termine |
| `3` | Abilita/disabilita diagnostica estesa (tracing dettagliato ingresso/uscita funzioni per lo sviluppatore) |
| `4` | Scan continuo slave presenti/assenti (termina con `q`) |
| `5` | Abilita/disabilita modalità OTA via web |
| `6` | Stampa MAC address della scheda |
| `99` | Esce dal menu |

Esempio di output del comando `2`: (n. allarmi, letture presenza in rete ok, letture presenza in rete fallite)
```
Slave2 ALRM=3 OK=6403 NON_OK=2
Slave3 ALRM=0 OK=0    NON_OK=6405
Slave4 ALRM=0 OK=0    NON_OK=6405
Slave5 ALRM=0 OK=0    NON_OK=6405
```

---

## 6. Aggiornamento firmware via OTA

Il firmware include un web server OTA (`WebServer` + libreria `Update.h`) sempre disponibile sull'IP del master, protetto da autenticazione HTTP Basic.

**Procedura completa:**
1. Scaricare il file (`.bin`) aggiornato .
2. Salvarlo in una cartella nota .
3. Scollegare il PC dalla rete del router e collegarlo alla rete WiFi `88888888` pass `88888888`` .
4. Aprire una sessione Telnet verso `192.168.4.1:2323`.  (Da prompt CMD scrivere "telnet 192.168.4.1 2323")
5. Autenticarsi con user 'admin' e password Pautax2006.
6. Inviare `m` per aprire il menu diagnostico.
7. Inviare `5` per attivare la modalità OTA.   ??????? verificare procedura
8. Aprire nel browser `http://192.168.4.1/update` (**http**, non https).
9. Inserire le credenziali OTA (username admin, password Pautax2006).
10. Sulla pagina web con sfoglia, cercare su disco il file `.bin`.
11. Attendere il completamento dell'upload.
12. Attendere il riavvio automatico della scheda.
13. Verificare il corretto funzionamento del nuovo firmware.

Durante l'OTA il master entra in **modalità manutenzione** (il polling/le funzioni normali sono sospese).

---

## 7. Struttura firmware e file di progetto

```
4MASTER32/
├── 4MASTER32_startup_03_88888888.ino      # sketch di primo avvio / recovery (OTA + seriale)
├── 4MASTER32_displ_pir_wdog_100.ino.bin   # firmware vero e proprio  
```

### 7.1 Sketch di primo avvio (`4MASTER32_startup_02_88888888.ino`)
Lo sketch *startup* è una **variante minimale di primo avvio / recovery**: monta solo l'Access Point WiFi, il web server OTA e il watchdog hardware, stampando periodicamente sulla seriale un messaggio di invito ad aggiornare il firmware. **Non contiene** la logica di polling degli slave, display e relè descritta nel manuale: è pensato per flashare facilmenete una scheda "vergine" (o recuperare una scheda bloccata) e portarla via OTA al firmware applicativo completo, senza dover ricollegarla via USB.

Elementi tecnici principali:
- Watchdog hardware task (`esp_task_wdt`), timeout 8 s, con `trigger_panic` attivo — se il loop si blocca, la scheda si resetta da sola.
- Web server OTA (`WebServer` su porta 80) con autenticazione HTTP Basic.
- Endpoint `/update` per upload del binario, gestito in streaming (`UPLOAD_FILE_START` / `WRITE` / `END` / `ABORTED`) con log di avanzamento su seriale.
- Riavvio automatico (`ESP.restart()`) 1,5 s dopo il completamento dell'OTA.

### 7.2 `Master_ID.h`
Definisce l'identità del master sulla rete e i parametri di rete/console:
- `MASTER_ID` — fisso a `1` (gli slave usano 2–9, max 8 slave in rete).
- SSID / password dell'Access Point del master.
- IP statico, gateway, subnet dell'AP.
- Porta TCP applicativa, porta e password della console Telnet diagnostica.
- Porta, utente e password del web server OTA.
- `NUM_SLAVES`, `FIRST_SLAVE_ID` — numero e primo ID degli slave attesi in rete.
- Un promemoria empirico sulle misure di livello del segnale radio (es. a 30 cm circa −33 dB, a 7 m circa −85/−92 dB), utile per capire i limiti della portata dell'AP in fase di progettazione dell'impianto.

NOTA BENE: questo file non è accessibile, ma contenuto nel file .bin .

### 7.3 `Scelta dei parametri SSID e PASSWORD WiFi`
- Il nome della rete locale (SSID) e della password WiFi desiderate devono essere richieste all'indirizzo register@realmeteo.com , unitamente al MAC Address della scheda ESP32-C3, leggibile dal menù di servizio con il comando 6.
- Questi parametri (SSID e PASSWORD) dovranno essere riportati identici sul file Slave_ID.h prima di programmare i moduli SLAVE (WEMOS LIOLIN D1), editando queste due linee
- const char* WIFI_SSID = "NOME-DESIDERATO-RETE-WIFI";
- const char* WIFI_PASS = "PASSWORD-WIFI";

### 7.4 `Nota tecnica: partitions.csv`
Tabella di partizionamento flash ESP32-c3, schema **OTA dual-app** (necessario per gli aggiornamenti OTA sicuri, con rollback):

| Nome | Tipo | Sub-tipo | Offset | Dimensione |
|---|---|---|---|---|
| `nvs` | data | nvs | `0x9000` | 20 KB |
| `otadata` | data | ota | `0xe000` | 8 KB |
| `app0` | app | ota_0 | `0x10000` | 1900 KB |
| `app1` | app | ota_1 | — | 1900 KB |
| `coredump` | data | coredump | — | 128 KB |

Due slot applicativi (`app0`/`app1`) da 1900 KB ciascuno permettono all'OTA di scrivere il nuovo firmware nello slot inattivo e passare a quello solo dopo un upload riuscito, mantenendo la possibilità di tornare al firmware precedente in caso di problemi. La partizione `coredump` conserva un dump in caso di crash per facilitare il debug.

---

## 8. Riprodurre il progetto: cosa serve

**Hardware:**
- Scheda ESP32‐C3 con display OLED da 0,42 pollici WiFi Bluetooth
- PCB
-Relè
- Sensori PIR e schede slave D1 dedicate (una per ogni punto da monitorare)
- 2 LED (bordo + ausiliario su GPIO 9)
- 2 ponticelli/pulsanti verso GND su GPIO 4 e GPIO 10

ESP32-C3 

**Toolchain:**
- Arduino IDE con core ESP32 installato ed impostazione del file "http://arduino.esp8266.com/stable/package_esp8266com_index.json" nelle preferenze
- Librerie: `WiFi.h`, `WebServer.h`, `Update.h`, `esp_task_wdt.h` (incluse nel core ESP32, nessuna installazione aggiuntiva richiesta)

**Programmazione scheda MASTER:**
0. Scaricare tutti i files presenti nella cartella firmware, copiandoli in una cartella nota sul nostro pc.
0.1 Opzionale ma preferibile: Smontare la scheda ESP32 C3 dalla board e connetterla al pc tramite il cavetto USB
1. Su Arduino IDE2 , impostare quanto segue: 
1.1 File->Preferences-> Additional board manager url-> http://arduino.esp8266.com/stable/package_esp8266com_index.jsonze 
1.2 Board "ESP32‐C3 Dev Module"
1.3 Tools-> Erase all flash before upload ->Enabled
1.4 Tools-> USB CDC on boot -> Enabled 
2. Aprire lo sketch "4MASTER32_startup_02_88888888.ino" e caricarlo su una scheda ESP32C3 (meglio se con display OLED da 0,42 pollici).
2.1 Verificare da terminale seriale a 115200 baud il seguente messaggio:  =========================================
SoftAP avviato - SSID: 88888888
IP per aggiornamento OTA: http://192.168.4.1
=========================================
eseguire aggiornamento OTA

3. Verificare con il PC che tra le altre reti WiFi ci sia anche la rete con SSID = **88888888** (si legge INTERNET NON DISPONIBILE). 
4. Scollegare il PC dalla rete wifi del vostro router e collegare la rete con SSID 88888888 usando password 88888888
5. Sul browser del pc digitare il seguente indirizzo (opzionalmente lasciare il monitor seriale attivo) http://192.168.4.1/update   (attenzione, non https) 
5.1 Verrà richiesto di autenticarsi: user 'admin' password 'Pautax2006' 
6. Con sfoglia/browse cercare il file 4MASTER32_displ_pir_wdog_100.bin (N.B. 100 è la versione, potreste anche trovare un upgrade con altro numero) .
6.1 Programmare la scheda con il pulsante 'Carica Firmware'
6.2 sul terminae seriale si legge:
OTA: Upload firmware avviato.
OTA: File = 4MASTER32_displ_pir_wdog_100.ino.bin
OTA: Upload completato. Byte ricevuti: 1072240
OTA: aggiornamento completato. Riavvio in corso...
eseguire aggiornamento OTA
Riavvio dispositivo in corso...
6.3 sul browser si legge: **Aggiornamento completato. Il master si riavvia.**

---

## 9. PCB

- I PCB per montare schede MASTER e SLAVE sono in sviluppo e verranno distribuiti a `prezzo di costo`, se sei interessato prenotati.

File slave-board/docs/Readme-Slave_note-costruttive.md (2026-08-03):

# PIR Slave — ESP8266 / Wemos D1 mini (v100INV)

Documentazione completa del nodo **Slave** del sistema di allarme/ripetitore PIR Master-Slave.

Questo documento descrive hardware, pinout, configurazione Arduino IDE, protocollo di comunicazione, comportamento dei LED, logica di allarme e procedure di test. È pensato per chi deve programmare, collaudare o manutenere uno Slave già funzionante.

---

## 1. Panoramica

| Voce | Valore |
|---|---|
| Microcontrollore | ESP8266 (Wemos D1 mini / LOLIN D1 mini clone) |
| Ruolo | Rileva allarme PIR, memorizza lo stato (latch), risponde al Master via TCP |
| Rete | Wi-Fi 802.11b, topologia a stella, IP statico |
| Porta TCP | **4210** |
| Watchdog | Software ESP8266, timeout 8 secondi |
| Firmware di riferimento | `4SLAVE8266_pir_LR_wdog_100INV.ino` |

**Principio di funzionamento**

1. All'avvio esegue  un countdown di 90 s per il riscaldamento del PIR, ad evitare falsi allarme in caso caduta rete 220V (escludibile inserendo il jumper su D6).
2. Quando il PIR rileva un movimento alza un flag di allarme **latched** e accende il LED diagnostico.
3. Il Master interroga periodicamente lo Slave via TCP (porta 4210).
4. Lo Slave risponde con `STA100` (normale) o `STA113` (allarme latched), più contatore chiamate e RSSI.
5. Il flag di allarme **non** viene azzerato dal semplice polling: si azzera **solo** ricevendo il comando `155` / `STA155` (via TCP dal Master o seriale).

---

## 2. Hardware e Pinout

### 2.1 Scheda

- **Wemos D1 mini** (o clone LOLIN) basata su ESP-12E/F.
- Alimentazione tipica: 5 V via USB oppure 3,3 V stabilizzato.
- LED built-in sulla scheda (attivo LOW).

### 2.2 Pin utilizzati

| Pin Wemos | GPIO | Funzione | Note |
|---|---|---|---|
| D5 | GPIO14 | Input PIR | INPUT_PULLUP |
| D6 | GPIO12 | SkipDelayPir | INPUT_PULLUP — a GND salta i 90 s di warmup |
| D7 | GPIO13 | LED Diagnostico Allarme | Uscita attiva HIGH (anodo LED → resistore → D7, catodo → GND) |
| LED_BUILTIN | GPIO2 | LED attività | Attivo LOW |

### 2.3 Collegamenti consigliati

**Sensore PIR**
- Uscita del PIR (o contatto/opto) collegata a **D5** tramite optoisolatore come da schema elettrico.
- Logica configurabile con la costante `PirReverse` nel `.ino`:
  - `false` → allarme quando D5 legge HIGH
  - `true` → allarme quando D5 legge LOW (utile con contatto NC in serie a optoisolatore)

**LED diagnostico allarme**
- D7 → resistore 330–1 kΩ → anodo LED ; catodo LED → GND

**Ponticello Skip warmup**
- D6 → GND (solo all'accensione, per saltare i 90 s di riscaldamento PIR durante il collaudo board)

---

## 3. Configurazione Arduino IDE

### 3.1 Board e impostazioni

1. Installa il core **ESP8266** (Board Manager → cerca "esp8266" di ESP8266 Community).
2. Seleziona la board:
   - **LOLIN(WEMOS) D1 mini (clone)**
   oppure
   - **NodeMCU 1.0 (ESP-12E Module)** (funziona ugualmente su molti clone)
3. Impostazioni consigliate:
   - **CPU Frequency**: 80 MHz
   - **Flash Size**: 4 MB (FS: 2 MB OTA:~1019 KB) o analogo
   - **Upload Speed**: 921600 (o 115200 se instabile)
   - Nessuna opzione "USB CDC on boot" richiesta (la seriale passa sempre dal CH340).

### 3.2 Librerie necessarie

- **ESP8266WiFi** (già inclusa nel core)
- **Wire** (già inclusa nel core)

### 3.3 File di configurazione `Slave_ID.h`

Questo è l'unico file da modificare per creare 4 Slave diversi (`#define SLAVE_ID 2` // oppure 3, 4, 5).

```cpp
// Slave_ID.h
// board WEMOS LOLIN D1 clone
#ifndef SLAVE_ID_H
#define SLAVE_ID_H

#define SLAVE_ID 3 // valore da 2 a 5

// Controllo a tempo di compilazione: se fuori range, la compilazione si blocca
static_assert(SLAVE_ID >= 2 && SLAVE_ID <= 5, "SLAVE_ID deve essere compreso tra 2 e 5");

#endif

// ===================== CONFIGURAZIONE WIFI =====================

const char* WIFI_SSID = "WINDTRE-6EF994";
const char* WIFI_PASS = "7DHH383KKK33-2a";

IPAddress AP_IP(192, 168, 4, 1);
IPAddress GATEWAY(192, 168, 4, 1);
IPAddress SUBNET(255, 255, 255, 0);

// L'ultimo ottetto è preso direttamente da SLAVE_ID:
// non serve (e non bisogna) modificare manualmente l'IP.
IPAddress STATIC_IP(192, 168, 4, SLAVE_ID);

const uint16_t TCP_PORT = 4210;
WiFiServer tcpServer(TCP_PORT);
const float RangeOptimizedTxPowerDbm = 20.5f;
const WiFiPhyMode_t RangeOptimizedPhyMode = WIFI_PHY_MODE_11B;
```

L'indirizzo IP viene calcolato automaticamente:

| SLAVE_ID | IP assegnato automaticamente |
|---|---|
| 2 | 192.168.4.2 |
| 3 | 192.168.4.3 |
| 4 | 192.168.4.4 |
| 5 | 192.168.4.5 |

Il Master resta sempre su `192.168.4.1`.

Non è necessario (e non è consigliato) modificare a mano `STATIC_IP`: il costruttore `IPAddress(192, 168, 4, SLAVE_ID)` garantisce l'allineamento tra ID logico e indirizzo di rete. Se si inserisce un valore fuori da 2–5, la compilazione fallisce grazie a `static_assert`.

SSID e password Wi-Fi vanno impostati nello stesso file (`WIFI_SSID` / `WIFI_PASS`).

### 3.4 Upload

1. Collega la Wemos via USB.
2. Seleziona la porta COM corretta.
3. Carica lo sketch.
4. Apri il Monitor Seriale a 115200 baud.

All'avvio vedrai:
- nome del file `.ino`
- messaggio di attivazione watchdog
- stato del pin SkipDelayPir
- countdown PIR (se non saltato)
- tentativo di connessione Wi-Fi
- "Setup completato, avvio loop."

---

## 4. Logica di funzionamento dettagliata

### 4.1 Avvio e riscaldamento PIR

- Se D6 non è a GND → countdown di 90 secondi.
- Ogni secondo il LED_BUILTIN esegue un doppio blink (vedi sezione LED).
- Se D6 è a GND → il delay viene saltato (utile in fase di test).

### 4.2 Rilevamento allarme (Latch)

- La funzione `updatePirLatch()` legge continuamente D5.
- Alla prima rilevazione di allarme:
  - `pirAlarmLatched = true`
  - LED diagnostico (D7) acceso
  - messaggio seriale di conferma
- Il flag rimane alto anche se il PIR torna a riposo.
- Solo il comando di reset lo spegne.

### 4.3 Risposta al Master (TCP)

Quando arriva una connessione TCP sulla porta 4210 lo Slave:

1. Invia immediatamente:
   ```
   Id=<SLAVE_ID>
   STA100          oppure STA113
   CALL=<n> RADIO=<rssi>db
   ```
2. Se lo stato inviato era di allarme (STA113), attende fino a 500 ms un eventuale comando di reset (`155`).
3. Se riceve `155` → esegue `resetAlarmFlag()` (flag = false + LED D7 spento).
4. Chiude la connessione.

> **Importante**: il semplice polling non resetta l'allarme. Solo il codice `155` lo fa.

### 4.4 Comandi seriali (debug)

Con il Monitor Seriale aperto:

| Comando | Azione |
|---|---|
| `?` | Simula una chiamata del Master (stampa la stessa risposta che andrebbe via TCP) |
| `155` | Reset immediato del flag di allarme e spegnimento LED diagnostico (o qualsiasi stringa che contenga 155) |

### 4.5 Watchdog

- Abilitato in setup con timeout di 8 secondi (`ESP.wdtEnable(WDTO_8S)`).
- Alimentato (`ESP.wdtFeed()`) in tutti i punti critici (loop, delay lunghi, lettura TCP, ecc.).
- In caso di blocco del codice la scheda si riavvia autonomamente.

### 4.6 Riconnessione Wi-Fi

Se la connessione viene persa, ogni 5 secondi lo Slave tenta di riconnettersi in background senza bloccare il loop.

---

## 5. LED — Comportamento completo

### 5.1 LED_BUILTIN (GPIO2, attivo LOW)

| Situazione | Comportamento |
|---|---|
| Risposta al Master (TCP o `?`) | Toggle dello stato (1 cambio di stato) |
| Countdown riscaldamento PIR | Doppio blink ogni secondo: ON 120 ms → OFF 120 ms → ON 120 ms → ripristino stato + pausa 640 ms |
| Pattern a 3 o 4 blink | Non implementati |

### 5.2 LED Diagnostico Allarme (D7, attivo HIGH)

| Evento | Azione |
|---|---|
| PIR rileva allarme | Si accende e resta acceso |
| Polling del Master | Resta acceso (il polling del Master non lo spegne) |
| Ricezione comando `155` / `STA155` | Si spegne |

---

## 6. Protocollo di comunicazione (riepilogo)

**Richiesta Master → Slave**

Semplice connessione TCP alla porta 4210 (nessun payload obbligatorio).

**Risposta Slave → Master**

```
Id=3
STA100
CALL=15 RADIO=-67db
```

oppure

```
Id=3
STA113
CALL=16 RADIO=-65db
```

**Reset allarme (Master → Slave, solo se lo Slave ha appena inviato STA113)**

```
155
```
(o qualsiasi riga contenente la sottostringa `155`)

---

## 7. Collaudo di uno Slave già funzionante

1. Alimentare la scheda e aprire il Monitor Seriale a 115200.
2. Verificare che compaia il messaggio di setup e l'IP statico (192.168.4.x dove x = SLAVE_ID).
3. Inviare `?` dalla seriale → deve rispondere con STA100 e mostrare il contatore CALL.
4. Attivare il PIR (o simulare il segnale su D5) → il LED su D7 deve accendersi e la seriale deve segnalare l'allarme.
5. Inviare di nuovo `?` → deve rispondere STA113.
6. Inviare `155` → il LED D7 si spegne e lo stato torna normale.
7. Verificare che il Master (se presente) veda correttamente lo stato e riesca a inviare il reset.

**Test rapido senza Master**

Tutto può essere collaudato solo con seriale + PIR + LED, senza necessità della rete.

---

## 8. Note operative e consigli

- Per massimizzare la portata radio lo Slave forza la modalità 802.11b e potenza TX a 20,5 dBm, con sleep radio disabilitato.
- Il latch di allarme è deliberato: evita di perdere un evento breve se il Master non interroga esattamente in quel momento.
- Il timeout di attesa del comando 155 dopo una risposta di allarme è di soli 500 ms: il Master deve essere abbastanza reattivo.
- Per creare un nuovo Slave è sufficiente modificare `SLAVE_ID` in `Slave_ID.h` e ricaricare lo sketch. L'IP si aggiorna da solo.
- Il ponticello D6→GND è utilissimo in laboratorio; in installazione definitiva va rimosso.
- La porta TCP usata dal sistema è 4210 (non 80).

---

## 9. File correlati

| File | Contenuto |
|---|---|
| `4SLAVE8266_pir_LR_wdog_100INV.ino` | Firmware completo Slave |
| `Slave_ID.h` | Identificativo, credenziali Wi-Fi, IP statico automatico, porta TCP 4210 |
| `README.md` | Documentazione operativa e di programmazione |

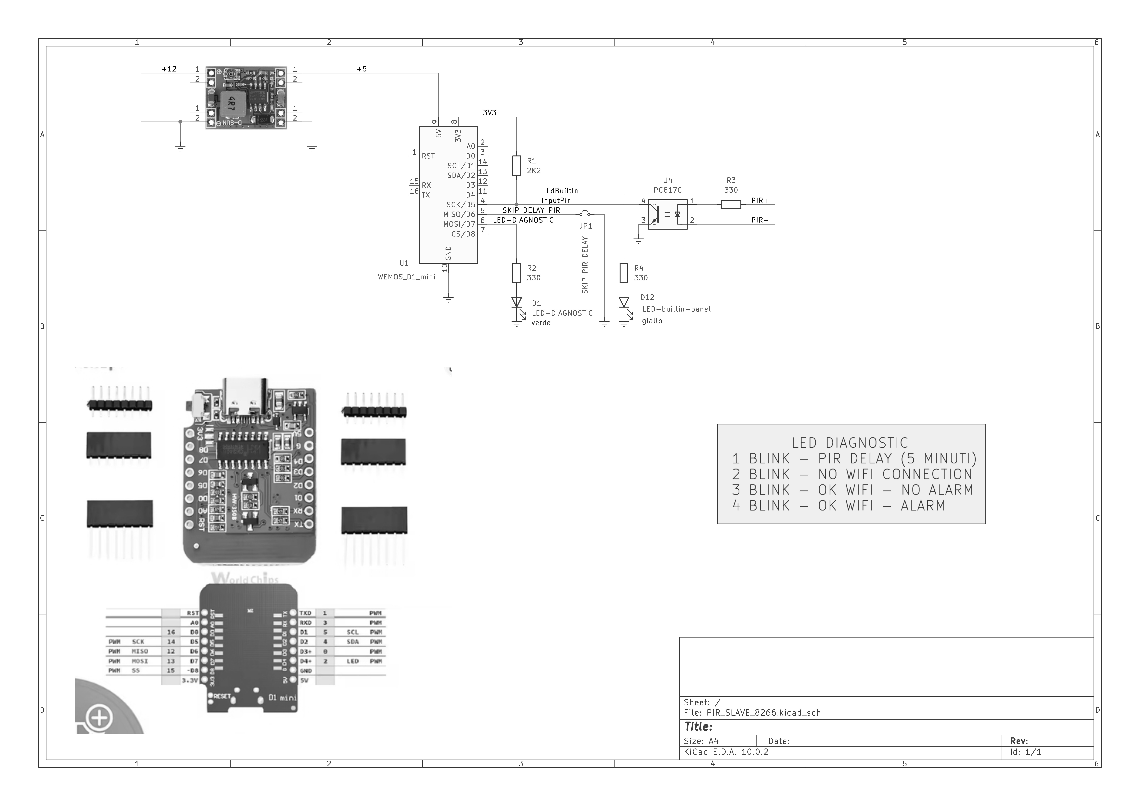
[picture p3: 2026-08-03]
slave-board/hardware/SLAVE-8266-SCHEMATIC.jpg

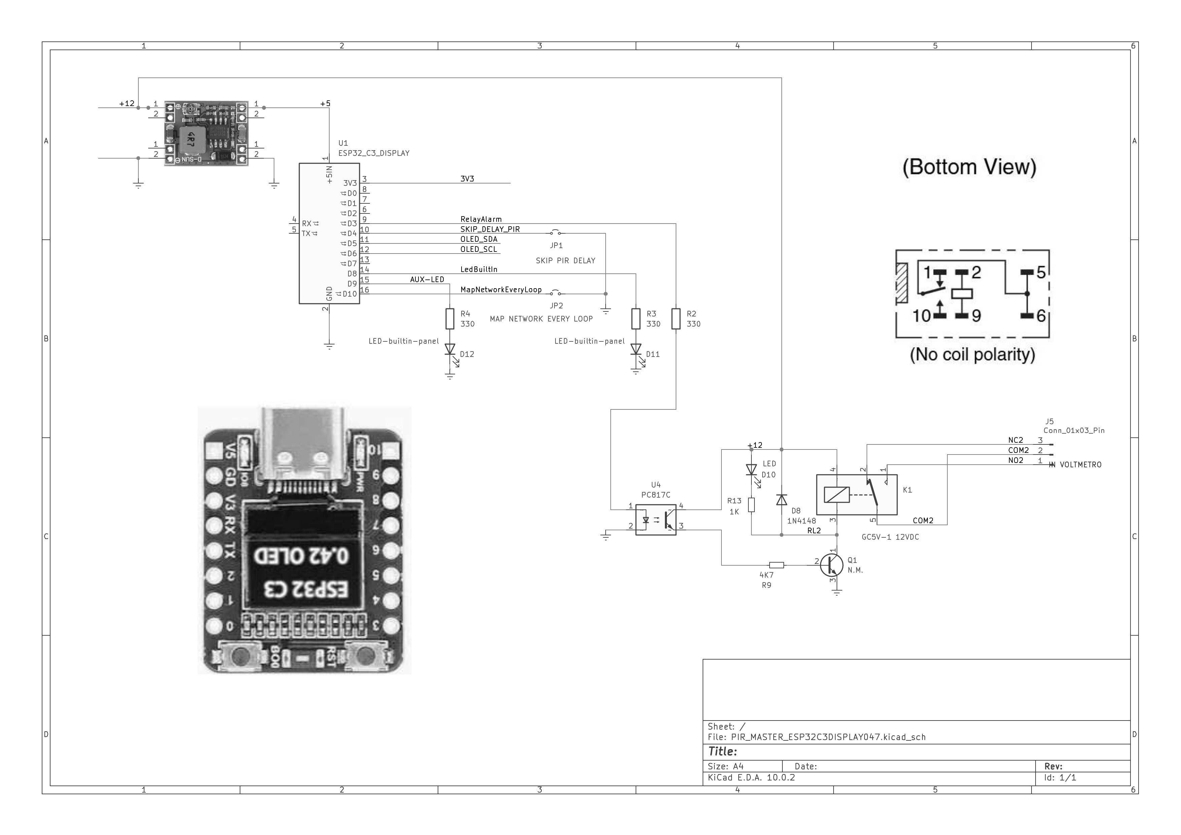
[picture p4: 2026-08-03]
master-board/hardware/MASTER-ESP32C3-DISPLAY-SCHEMATIC.jpg

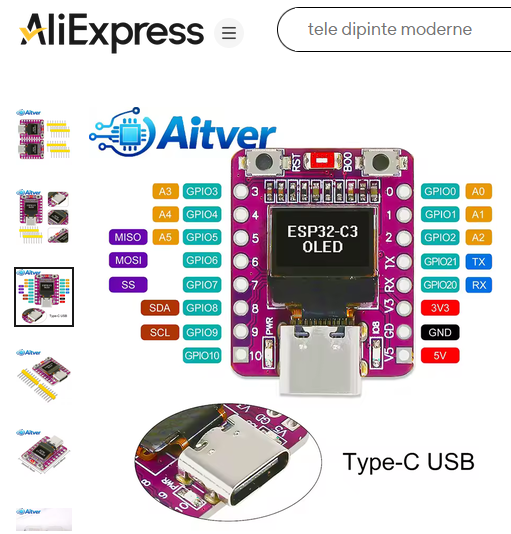
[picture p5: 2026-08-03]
master-board/docs/ESP32-C3.png

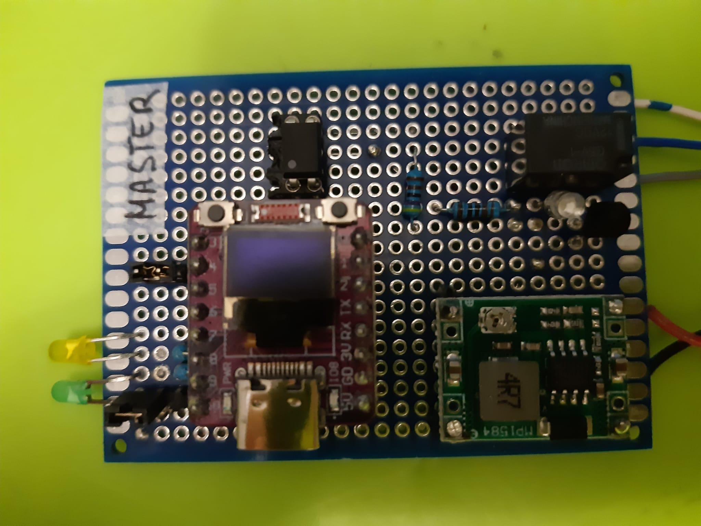
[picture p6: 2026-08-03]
foto prototipi/Master board 1 proto.jpg

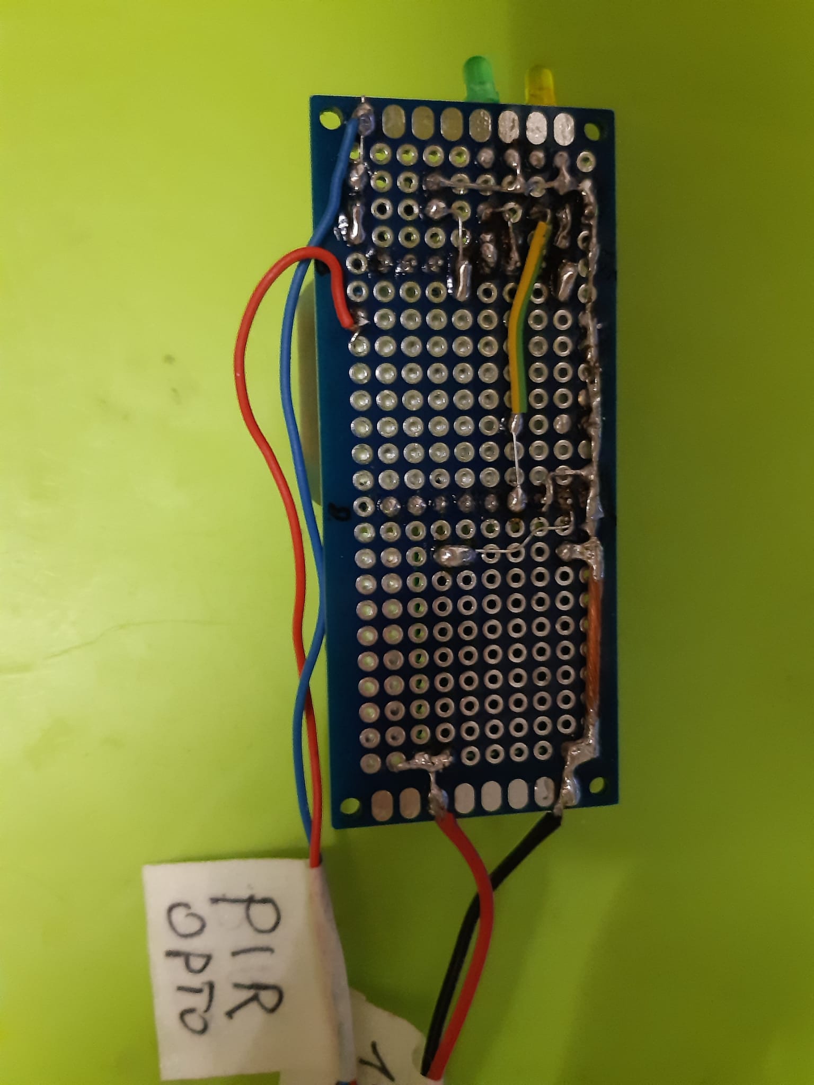
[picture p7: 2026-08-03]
foto prototipi/Slave board 2.jpg

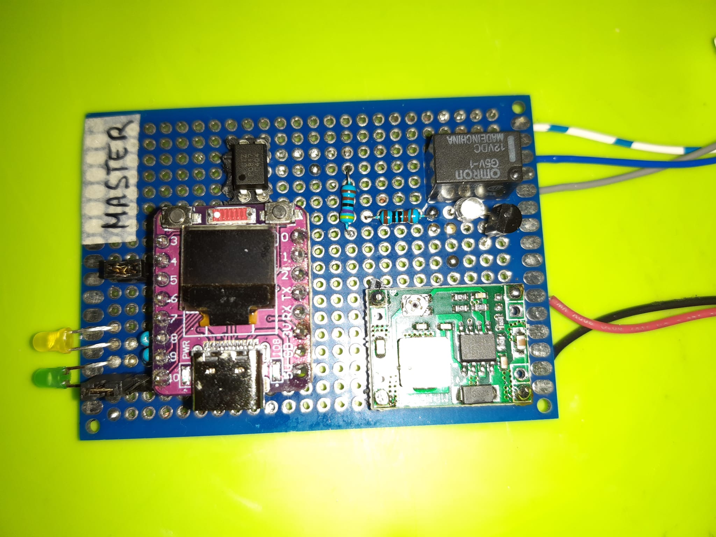
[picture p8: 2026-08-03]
foto prototipi/Master board 3.jpg

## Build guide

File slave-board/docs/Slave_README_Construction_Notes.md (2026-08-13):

# PIR Slave — ESP8266 / Wemos D1 mini (v100INV)

Complete documentation of the **Slave** node of the Master-Slave PIR alarm/repeater system.

This document describes hardware, pinout, Arduino IDE configuration, communication protocol, LED behaviour, alarm logic and test procedures. It is intended for anyone who needs to program, test or maintain an already working Slave.

---

## 1. Overview

| Item | Value |
|---|---|
| Microcontroller | ESP8266 (Wemos D1 mini / LOLIN D1 mini clone) |
| Role | Detects PIR alarm, stores the state (latch), replies to the Master via TCP |
| Network | Wi-Fi 802.11b, star topology, static IP |
| TCP Port | **4210** |
| Watchdog | ESP8266 software, 8-second timeout |
| Reference firmware | `4SLAVE8266_pir_LR_wdog_100INV.ino` |

**Operating principle**

1. At start-up it runs a 90-second countdown for PIR warm-up, to avoid false alarms in case of 220 V power loss (can be skipped by inserting the jumper on D6).
2. When the PIR detects movement it raises a **latched** alarm flag and turns on the diagnostic LED.
3. The Master periodically polls the Slave via TCP (port 4210).
4. The Slave replies with `STA100` (normal) or `STA113` (latched alarm), plus call counter and RSSI.
5. The alarm flag is **not** cleared by a simple poll: it is cleared **only** when receiving the command `155` / `STA155` (via TCP from the Master or via serial).

---

## 2. Hardware and Pinout

### 2.1 Board

- **Wemos D1 mini** (or LOLIN clone) based on ESP-12E/F.
- Typical power supply: 5 V via USB or stabilised 3.3 V.
- On-board built-in LED (active LOW).

### 2.2 Pins used

| Wemos Pin | GPIO | Function | Notes |
|---|---|---|---|
| D5 | GPIO14 | PIR Input | INPUT_PULLUP |
| D6 | GPIO12 | SkipDelayPir | INPUT_PULLUP — to GND skips the 90 s warm-up |
| D7 | GPIO13 | Alarm Diagnostic LED | Active HIGH output (LED anode → resistor → D7, cathode → GND) |
| LED_BUILTIN | GPIO2 | Activity LED | Active LOW |

### 2.3 Recommended connections

**PIR sensor**
- PIR output (or contact/opto) connected to **D5** through an optoisolator as per the electrical schematic.
- Logic configurable with the `PirReverse` constant in the `.ino`:
  - `false` → alarm when D5 reads HIGH
  - `true` → alarm when D5 reads LOW (useful with NC contact in series with optoisolator)

**Alarm diagnostic LED**
- D7 → 330–1 kΩ resistor → LED anode; LED cathode → GND

**Skip warm-up jumper**
- D6 → GND (only at power-on, to skip the 90 s PIR warm-up during board testing)

---

## 3. Arduino IDE Configuration

### 3.1 Board and settings

1. Install the **ESP8266** core (Board Manager → search for "esp8266" by ESP8266 Community).
2. Select the board:
   - **LOLIN(WEMOS) D1 mini (clone)**
   or
   - **NodeMCU 1.0 (ESP-12E Module)** (works equally well on many clones)
3. Recommended settings:
   - **CPU Frequency**: 80 MHz
   - **Flash Size**: 4 MB (FS: 2 MB OTA:~1019 KB) or similar
   - **Upload Speed**: 921600 (or 115200 if unstable)
   - No "USB CDC on boot" option required (serial always goes through the CH340).

### 3.2 Required libraries

- **ESP8266WiFi** (already included in the core)
- **Wire** (already included in the core)

### 3.3 Configuration file `Slave_ID.h`

This is the only file that needs to be modified to create 4 different Slaves (`#define SLAVE_ID 2` // or 3, 4, 5).

```cpp
// Slave_ID.h
// board WEMOS LOLIN D1 clone
#ifndef SLAVE_ID_H
#define SLAVE_ID_H

#define SLAVE_ID 3 // value from 2 to 5

// Compile-time check: if out of range, compilation fails
static_assert(SLAVE_ID >= 2 && SLAVE_ID <= 5, "SLAVE_ID must be between 2 and 5");

#endif

// ===================== WIFI CONFIGURATION =====================

const char* WIFI_SSID = "WINDTRE-6EF994";
const char* WIFI_PASS = "7DHH383KKK33-2a";

IPAddress AP_IP(192, 168, 4, 1);
IPAddress GATEWAY(192, 168, 4, 1);
IPAddress SUBNET(255, 255, 255, 0);

// The last octet is taken directly from SLAVE_ID:
// there is no need (and you must not) manually modify the IP.
IPAddress STATIC_IP(192, 168, 4, SLAVE_ID);

const uint16_t TCP_PORT = 4210;
WiFiServer tcpServer(TCP_PORT);
const float RangeOptimizedTxPowerDbm = 20.5f;
const WiFiPhyMode_t RangeOptimizedPhyMode = WIFI_PHY_MODE_11B;
```

The IP address is calculated automatically:

| SLAVE_ID | Automatically assigned IP |
|---|---|
| 2 | 192.168.4.2 |
| 3 | 192.168.4.3 |
| 4 | 192.168.4.4 |
| 5 | 192.168.4.5 |

The Master always stays on `192.168.4.1`.

It is not necessary (and not recommended) to manually modify `STATIC_IP`: the constructor `IPAddress(192, 168, 4, SLAVE_ID)` guarantees alignment between the logical ID and the network address. If a value outside 2–5 is entered, compilation fails thanks to `static_assert`.

Wi-Fi SSID and password must be set in the same file (`WIFI_SSID` / `WIFI_PASS`).

### 3.4 Upload

1. Connect the Wemos via USB.
2. Select the correct COM port.
3. Upload the sketch.
4. Open the Serial Monitor at 115200 baud.

At start-up you will see:
- name of the `.ino` file
- watchdog activation message
- status of the SkipDelayPir pin
- PIR countdown (if not skipped)
- Wi-Fi connection attempt
- "Setup completed, starting loop."

---

## 4. Detailed Operating Logic

### 4.1 Start-up and PIR warm-up

- If D6 is not connected to GND → 90-second countdown.
- Every second the LED_BUILTIN performs a double blink (see LED section).
- If D6 is connected to GND → the delay is skipped (useful during testing).

### 4.2 Alarm detection (Latch)

- The function `updatePirLatch()` continuously reads D5.
- On the first alarm detection:
  - `pirAlarmLatched = true`
  - Diagnostic LED (D7) turns on
  - Serial confirmation message
- The flag remains high even if the PIR returns to rest.
- Only the reset command clears it.

### 4.3 Reply to the Master (TCP)

When a TCP connection arrives on port 4210 the Slave:

1. Immediately sends:
   ```
   Id=<SLAVE_ID>
   STA100          or STA113
   CALL=<n> RADIO=<rssi>db
   ```
2. If the status sent was an alarm (STA113), it waits up to 500 ms for a possible reset command (`155`).
3. If it receives `155` → it executes `resetAlarmFlag()` (flag = false + LED D7 off).
4. Closes the connection.

> **Important**: a simple poll does not reset the alarm. Only the code `155` does so.

### 4.4 Serial commands (debug)

With the Serial Monitor open:

| Command | Action |
|---|---|
| `?` | Simulates a Master call (prints the same response that would go via TCP) |
| `155` | Immediate reset of the alarm flag and turning off of the diagnostic LED (or any string containing 155) |

### 4.5 Watchdog

- Enabled in setup with an 8-second timeout (`ESP.wdtEnable(WDTO_8S)`).
- Fed (`ESP.wdtFeed()`) at all critical points (loop, long delays, TCP reading, etc.).
- In case of code lock-up the board restarts autonomously.

### 4.6 Wi-Fi reconnection

If the connection is lost, every 5 seconds the Slave attempts to reconnect in the background without blocking the loop.

---

## 5. LEDs — Complete Behaviour

### 5.1 LED_BUILTIN (GPIO2, active LOW)

| Situation | Behaviour |
|---|---|
| Reply to Master (TCP or `?`) | Toggle of state (1 state change) |
| PIR warm-up countdown | Double blink every second: ON 120 ms → OFF 120 ms → ON 120 ms → restore previous state + 640 ms pause |
| 3 or 4 blink patterns | Not implemented |

### 5.2 Alarm Diagnostic LED (D7, active HIGH)

| Event | Action |
|---|---|
| PIR detects alarm | Turns on and stays on |
| Master polling | Stays on (Master polling does not turn it off) |
| Reception of command `155` / `STA155` | Turns off |

---

## 6. Communication Protocol (summary)

**Master → Slave request**

Simple TCP connection to port 4210 (no mandatory payload).

**Slave → Master response**

```
Id=3
STA100
CALL=15 RADIO=-67db
```

or

```
Id=3
STA113
CALL=16 RADIO=-65db
```

**Alarm reset (Master → Slave, only if the Slave has just sent STA113)**

```
155
```
(or any line containing the substring `155`)

---

## 7. Testing an Already Working Slave

1. Power the board and open the Serial Monitor at 115200.
2. Verify that the setup message and the static IP appear (192.168.4.x where x = SLAVE_ID).
3. Send `?` from the serial → it must reply with STA100 and show the CALL counter.
4. Activate the PIR (or simulate the signal on D5) → the LED on D7 must turn on and the serial must report the alarm.
5. Send `?` again → it must reply STA113.
6. Send `155` → the D7 LED turns off and the status returns to normal.
7. Verify that the Master (if present) correctly sees the status and is able to send the reset.

**Quick test without Master**

Everything can be tested with only serial + PIR + LED, without needing the network.

---

## 8. Operating Notes and Tips

- To maximise radio range the Slave forces 802.11b mode and TX power at 20.5 dBm, with radio sleep disabled.
- The alarm latch is deliberate: it avoids losing a short event if the Master does not poll exactly at that moment.
- The timeout for waiting for the 155 command after an alarm response is only 500 ms: the Master must be sufficiently responsive.
- To create a new Slave it is sufficient to modify `SLAVE_ID` in `Slave_ID.h` and re-upload the sketch. The IP updates automatically.
- The D6→GND jumper is very useful in the laboratory; in the final installation it must be removed.
- The TCP port used by the system is 4210 (not 80).

---

## 9. Related Files

| File | Content |
|---|---|
| `4SLAVE8266_pir_LR_wdog_100INV.ino` | Complete Slave firmware |
| `Slave_ID.h` | Identifier, Wi-Fi credentials, automatic static IP, TCP port 4210 |
| `README.md` | Operational and programming documentation |

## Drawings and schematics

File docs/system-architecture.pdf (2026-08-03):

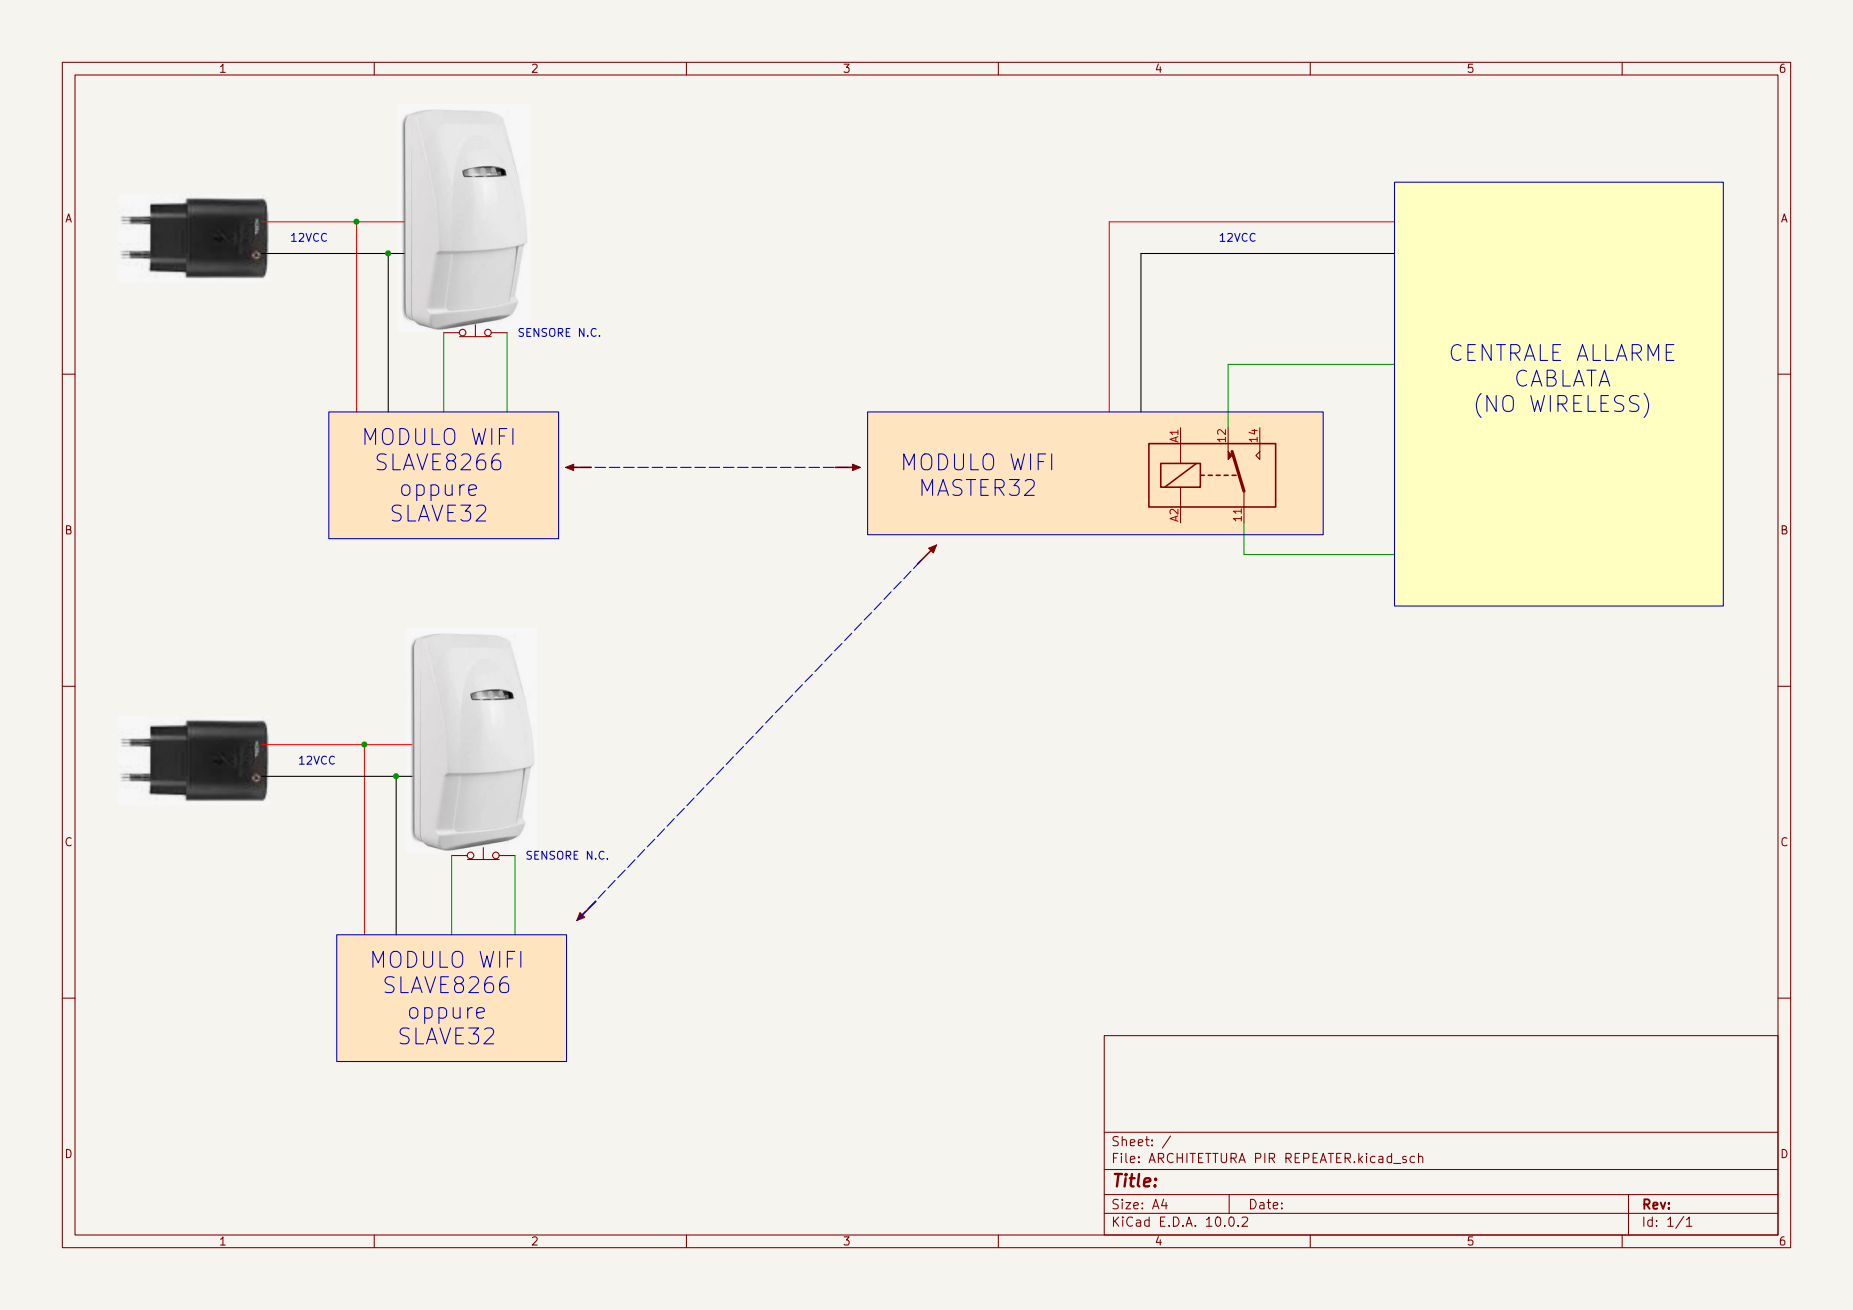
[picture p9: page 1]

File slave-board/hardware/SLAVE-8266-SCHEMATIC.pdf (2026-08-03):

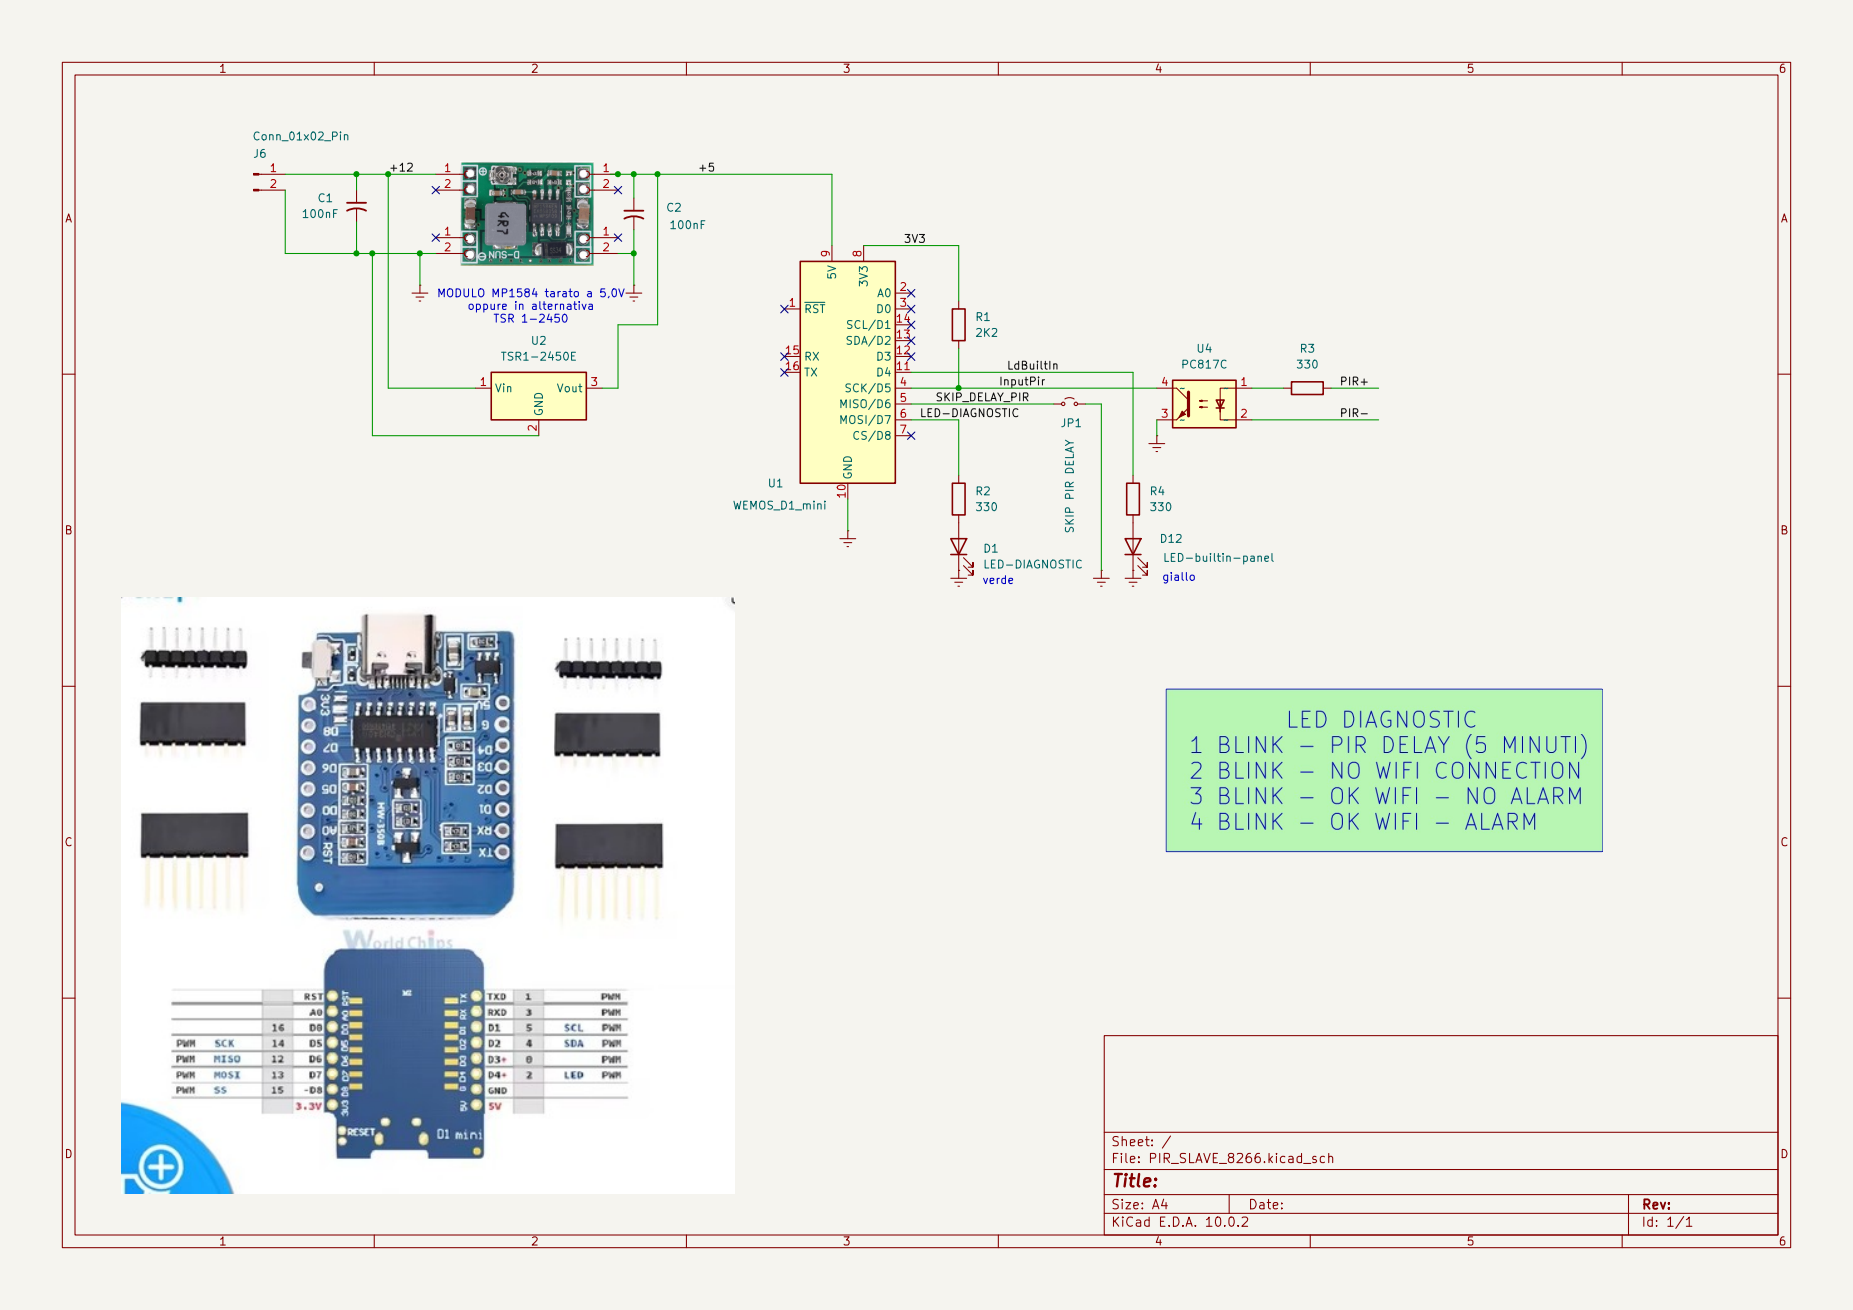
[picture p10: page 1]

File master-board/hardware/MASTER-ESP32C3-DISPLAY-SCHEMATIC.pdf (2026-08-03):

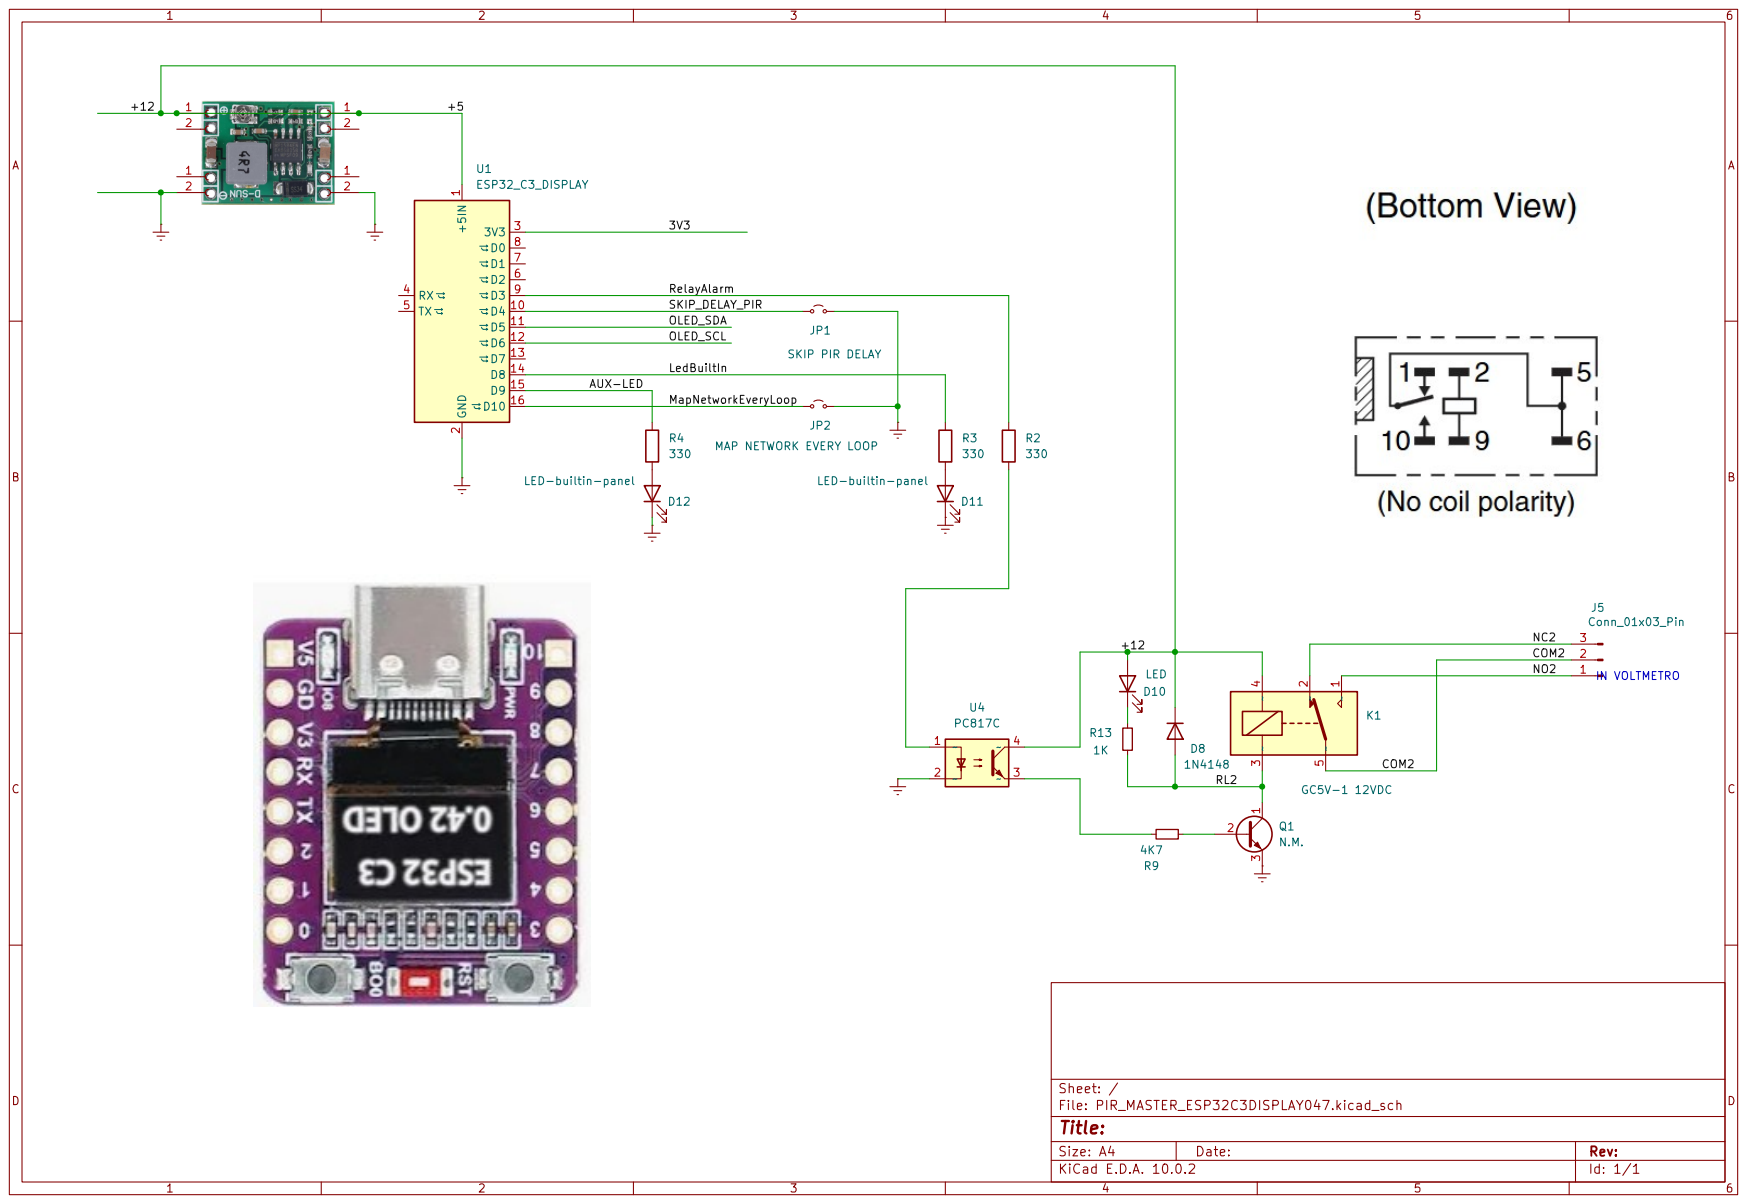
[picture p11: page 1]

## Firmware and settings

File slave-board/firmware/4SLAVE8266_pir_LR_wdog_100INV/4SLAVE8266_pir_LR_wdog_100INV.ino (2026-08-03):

/*
selezionare board "NodeMCU 1.0 (ESP-12e Module)"

100INV il flag di errore non viene resettato dal polling ma ricevendo il codice STA155
       ledDiag si accende e si spegne cn il flag allarme, 
70INV se usato con un PIR con contatto normalmente chiuso in serie all'opto pir
70 nuovo ssid e password
20 doppio blink diag led durante pir 
12 no-alarm sostituito da "STA100" ed alarm sostituito da "STA113"
11 trasmette numero di call master e db radio
10 wdog e stampa file ino

IMPOSTAZIONI ARDUINO IDE (Wemos D1 mini, ESP8266):
- Board: "LOLIN(WEMOS) D1 mini (clone)"
- CPU Frequency: 80MHz
- Nessuna opzione "USB CDC on boot" richiesta (seriale sempre attiva via CH340)
- Display OLED esterno da cablare: SDA->D2, SCL->D1, VCC->3V3, GND->GND
*/

#include <Wire.h>
#include <U8g2lib.h>
#include <ESP8266WiFi.h>
#include <string.h>

#include "Slave_ID.h" // identificazione del device

// ===================== DISPLAY =====================
// OLED esterno cablato su D2 (SDA) / D1 (SCL)
#define OLED_SDA D2
#define OLED_SCL D1
U8G2_SSD1306_72X40_ER_F_HW_I2C u8g2(U8G2_R0, U8X8_PIN_NONE, OLED_SCL, OLED_SDA);

// ===================== PIR - DELAY RISCALDAMENTO =====================

#define SkipDelayPir D6 // pull-up interno; a GND salta il delay
#define DelayPirSeconds 90 // secondi di attesa riscaldamento sensore PIR

// ===================== PIR - INGRESSO ALLARME =====================

#define InputPir D5 // pull-up interno
#define PirReverse false // se true: allarme quando InputPir legge 0 (e viceversa)

volatile bool pirAlarmLatched = false;

// Server TCP (dichiarazione mancante nello snippet originale ma necessaria)
// NOTA: WiFiServer tcpServer è già dichiarato all'interno di "Slave_ID.h" WiFiServer tcpServer(80);

// ===================== LED BUILTIN =====================

#define LED_BUILTIN_PIN LED_BUILTIN
#define LED_ACTIVE_LOW true

bool ledState = false;

void setLed(bool on) {
  digitalWrite(LED_BUILTIN_PIN, (on != LED_ACTIVE_LOW) ? HIGH : LOW);
}

void toggleLed() {
  ledState = !ledState;
  setLed(ledState);
}

void blinkWarmupDouble() {
  const bool savedLedState = ledState;

  setLed(true);
  feedWatchdog();
  delay(120);

  setLed(false);
  feedWatchdog();
  delay(120);

  setLed(true);
  feedWatchdog();
  delay(120);

  setLed(savedLedState);
  feedWatchdog();
  delay(640);
}


// ===================== LED DIAGNOSTICO ALLARME =====================
// D7 -> resistore -> anodo LED; catodo LED -> GND  (attivo HIGH)
#define LED_DIAG_PIN D7

void setDiagLed(bool on) {
  digitalWrite(LED_DIAG_PIN, on ? HIGH : LOW);
}

// ===================== VARIABILI GENERALI =====================

unsigned long lastDisplayUpdate = 0;
const unsigned long displayUpdateInterval = 200;
uint32_t masterPollCount = 0;

void feedWatchdog() {
  ESP.wdtFeed();
}

void initWatchdog() {
  ESP.wdtEnable(WDTO_8S);
  Serial.println("Watchdog software ESP8266 attivo: timeout lungo 8 s.");
}

const char* getSourceFileName() {
  const char* path = __FILE__;
  const char* base = path;

  while (*path != '\0') {
    if (*path == '/' || *path == '\\') {
      base = path + 1;
    }
    path++;
  }

  static char fileName[96];
  size_t len = strlen(base);

  if (len > 4 && strcmp(base + len - 4, ".cpp") == 0) {
    len -= 4;
  }

  if (len >= sizeof(fileName)) {
    len = sizeof(fileName) - 1;
  }

  memcpy(fileName, base, len);
  fileName[len] = '\0';
  return fileName;
}

void printSourceFileName() {
  Serial.print("File .ino: ");
  Serial.println(getSourceFileName());
}

// ===================== FUNZIONI PIR =====================

void countdownPir() {
  pinMode(SkipDelayPir, INPUT_PULLUP);
  delay(10);

  int pinState = digitalRead(SkipDelayPir);
  Serial.println();
  Serial.print("Slave id=");
  Serial.print(SLAVE_ID);
  Serial.print(" - Pin SkipDelayPir letto: ");
  Serial.println(pinState);

  if (pinState == 0) {
    Serial.println("Pin a GND -> delay riscaldamento PIR saltato.");
    return;
  }

  Serial.println("Avvio countdown riscaldamento PIR.");
  for (int t = DelayPirSeconds; t >= 0; t--) {
    Serial.print("id=");
    Serial.print(SLAVE_ID);
    Serial.print(" - Attesa riscaldamento PIR: ");
    Serial.print(t);
    Serial.println(" s");

    u8g2.clearBuffer();
    u8g2.setFont(u8g2_font_7x13_tf);
    char buf[10];
    snprintf(buf, sizeof(buf), "PIR %d", t);
    u8g2.drawStr(0, u8g2.getAscent(), buf);
    u8g2.sendBuffer();

    blinkWarmupDouble();
  }
  Serial.println("Countdown riscaldamento PIR completato.");
}

bool readPirAlarmNow() {
  int raw = digitalRead(InputPir);
  return PirReverse ? (raw == LOW) : (raw == HIGH);
}

void updatePirLatch() {
  if (readPirAlarmNow()) {
    if (!pirAlarmLatched) {
      Serial.print("id=");
      Serial.print(SLAVE_ID);
      Serial.println(" - ALLARME PIR rilevato -> flag alzato.");
      setDiagLed(true);
    }
    pirAlarmLatched = true;
  }
}

// ===================== WIFI =====================

void configureRangeOptimizedSta() {
  bool sleepOk = WiFi.setSleepMode(WIFI_NONE_SLEEP);
  bool phyOk = WiFi.setPhyMode(RangeOptimizedPhyMode);
  WiFi.setOutputPower(RangeOptimizedTxPowerDbm);

  Serial.print("id=");
  Serial.print(SLAVE_ID);
  Serial.println(" - Radio ottimizzata per massima distanza compatibile.");
  Serial.print("id=");
  Serial.print(SLAVE_ID);
  Serial.print(" - PHY 802.11b -> ");
  Serial.println(phyOk ? "OK" : "ERRORE");
  Serial.print("id=");
  Serial.print(SLAVE_ID);
  Serial.print(" - WIFI_NONE_SLEEP -> ");
  Serial.println(sleepOk ? "OK" : "ERRORE");
  Serial.print("id=");
  Serial.print(SLAVE_ID);
  Serial.print(" - TX power -> ");
  Serial.print(RangeOptimizedTxPowerDbm, 1);
  Serial.println(" dBm");
}

void setupWifi() {
  WiFi.mode(WIFI_STA);
  configureRangeOptimizedSta();
  WiFi.config(STATIC_IP, GATEWAY, SUBNET);
  WiFi.begin(WIFI_SSID, WIFI_PASS);

  Serial.print("id=");
  Serial.print(SLAVE_ID);
  Serial.print(" - Connessione a ");
  Serial.print(WIFI_SSID);
  Serial.print(" con IP ");
  Serial.println(STATIC_IP);

  unsigned long startAttempt = millis();
  while (WiFi.status() != WL_CONNECTED && millis() - startAttempt < 15000) {
    feedWatchdog();
    delay(300);
    Serial.print(".");
  }
  Serial.println();

  if (WiFi.status() == WL_CONNECTED) {
    Serial.print("id=");
    Serial.print(SLAVE_ID);
    Serial.print(" - Connesso, IP: ");
    Serial.println(WiFi.localIP());
  } else {
    Serial.print("id=");
    Serial.print(SLAVE_ID);
    Serial.println(" - Non connesso, ritento in background nel loop.");
  }

  tcpServer.begin();
}

void checkWifiReconnect() {
  static unsigned long lastAttempt = 0;
  if (WiFi.status() != WL_CONNECTED && millis() - lastAttempt > 5000) {
    lastAttempt = millis();
    Serial.print("id=");
    Serial.print(SLAVE_ID);
    Serial.println(" - WiFi disconnesso, tento riconnessione...");
    WiFi.disconnect();
    WiFi.begin(WIFI_SSID, WIFI_PASS);
  }
}

// ===================== RISPOSTA AL MASTER =====================

long getRadioDbForDebug() {
  return (WiFi.status() == WL_CONNECTED) ? WiFi.RSSI() : -99;
}

void respondToMaster(Print& dest, bool isRealMasterPoll) {
  bool statusToSend = pirAlarmLatched;
  uint32_t currentMasterPollCount = masterPollCount;
  long currentRadioDb = getRadioDbForDebug();

  if (isRealMasterPoll) {
    currentMasterPollCount = ++masterPollCount;
    currentRadioDb = getRadioDbForDebug();
  }

  dest.print("Id=");
  dest.println(SLAVE_ID);
  dest.println(statusToSend ? "STA113" : "STA100");
  dest.print("CALL=");
  dest.print(currentMasterPollCount);
  dest.print(" RADIO=");
  dest.print(currentRadioDb);
  dest.println("db");

  Serial.print("id=");
  Serial.print(SLAVE_ID);
  if (isRealMasterPoll) {
    Serial.print(" - Interrogazione master #");
    Serial.print(currentMasterPollCount);
    Serial.print(", stato trasmesso: ");
  } else {
    Serial.print(" - Chiamata seriale simulata, contatore master=");
    Serial.print(currentMasterPollCount);
    Serial.print(", stato trasmesso: ");
  }
  Serial.print(statusToSend ? "STA113" : "STA100");
  Serial.print(", info: C=");
  Serial.print(currentMasterPollCount);
  Serial.print(" R=");
  Serial.print(currentRadioDb);
  Serial.println("db");

  // RIMOZIONE: pirAlarmLatched non viene più resettato qui!

  toggleLed();
  feedWatchdog();
}

// ===================== RESET FLAG ALLARME =====================

void resetAlarmFlag() {
  pirAlarmLatched = false;
  setDiagLed(false);
  Serial.print("id=");
  Serial.print(SLAVE_ID);
  Serial.println(" - Ricevuto codice 155 -> FLAG ALLARME RESETTATO!");
}


// ===================== TCP =====================

// Timeout TCP (ms) — evita blocchi su client lenti/persi
const unsigned long TcpPostResponseMs = 500;  // attesa "155" dopo risposta se allarme

// Legge una riga fino a \n con timeout assoluto (no readStringUntil bloccante).
bool readLineWithTimeout(WiFiClient& client, String& out, unsigned long timeoutMs) {
  out = "";
  const unsigned long deadline = millis() + timeoutMs;
  while (millis() < deadline && client.connected()) {
    feedWatchdog();
    while (client.available()) {
      char c = (char)client.read();
      if (c == '\n') {
        out.trim();
        return true;
      }
      if (c != '\r' && out.length() < 64) {
        out += c;
      }
    }
    delay(1);
  }
  out.trim();
  return out.length() > 0;
}

void handleTcpClients() {
  WiFiClient client = tcpServer.available();
  if (!client) return;

  client.setNoDelay(true);
  client.setTimeout(TcpPostResponseMs);

  const bool sentAlarm = pirAlarmLatched;

  respondToMaster(client, true);
  client.flush();
  feedWatchdog();

  if (sentAlarm) {
    String command;
    if (readLineWithTimeout(client, command, TcpPostResponseMs)) {
      Serial.print("id=");
      Serial.print(SLAVE_ID);
      Serial.print(" - comando TCP ricevuto: [");
      Serial.print(command);
      Serial.println("]");
      if (command.indexOf("155") != -1) {
        resetAlarmFlag();
      }
    } else {
      Serial.print("id=");
      Serial.print(SLAVE_ID);
      Serial.println(" - timeout attesa 155 (latch NON resettato).");
    }
  }

  client.stop();
}

// ===================== SERIALE ("?" = polling simulato, "155" = reset) =====================

void handleSerialCommand() {
  static String inputBuf = "";
  while (Serial.available() > 0) {
    char c = (char)Serial.read();
    if (c == '\r') continue;
    if (c == '\n') {
      inputBuf.trim();
      if (inputBuf == "?") {
        respondToMaster(Serial, false);
      } else if (inputBuf.indexOf("155") != -1) {
        resetAlarmFlag();
      }
      inputBuf = "";
    } else if (inputBuf.length() < 48) {
      inputBuf += c;
    }
  }
}



// ===================== DISPLAY DI STATO =====================

void updateStatusDisplay() {
  bool wifiConnected = (WiFi.status() == WL_CONNECTED);

  u8g2.setFont(u8g2_font_7x13_tf);
  int charH = u8g2.getMaxCharHeight();
  int ascent = u8g2.getAscent();
  int lineStep = charH + 1;

  char line1[16];
  snprintf(line1, sizeof(line1), "%d %s", SLAVE_ID, wifiConnected ? "CONN" : "NOCN");

  const char* line2 = pirAlarmLatched ? "AL" : "OK";

  u8g2.clearBuffer();
  u8g2.drawStr(0, ascent, line1);
  u8g2.drawStr(0, ascent + lineStep, line2);
  u8g2.sendBuffer();
}

// ===================== SETUP =====================

void setup() {
  Serial.begin(115200);
  delay(1500);
  printSourceFileName();
  initWatchdog();

  u8g2.begin();
  u8g2.setContrast(255);
  u8g2.setBusClock(400000);

  Serial.print("=== Reset slave id=");
  Serial.print(SLAVE_ID);
  Serial.println(" ===");

  pinMode(LED_BUILTIN_PIN, OUTPUT);
  setLed(false);

  pinMode(LED_BUILTIN_PIN, OUTPUT);
  setLed(false);

  pinMode(LED_DIAG_PIN, OUTPUT);
  setDiagLed(false);


  countdownPir();

  pirAlarmLatched = false;

  pinMode(InputPir, INPUT_PULLUP);

  setupWifi();

  Serial.print("id=");
  Serial.print(SLAVE_ID);
  Serial.println(" - Setup completato, avvio loop.");
}

// ===================== LOOP =====================

void loop() {
  feedWatchdog();
  checkWifiReconnect();
  updatePirLatch();
  handleTcpClients();
  handleSerialCommand();

  if (millis() - lastDisplayUpdate >= displayUpdateInterval) {
    lastDisplayUpdate = millis();
    updateStatusDisplay();
  }
}

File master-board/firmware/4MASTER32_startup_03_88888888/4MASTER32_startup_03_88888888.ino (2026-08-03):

/* 
 * SKETCH MASTER - OTA & SERIAL ONLY
 * Modalità semplificata: Monitor Seriale + OTA sempre attivo
 */

#include <WiFi.h>
#include <WebServer.h>
#include <Update.h>
#include <esp_task_wdt.h>
#include "Master_ID.h"

// ===================== CONFIGURAZIONE SERVER OTA =====================

WebServer otaServer(OTA_HTTP_PORT);

bool otaUpdateInProgress = false;
bool otaUpdateSessionOpen = false;
bool otaUpdateFinishedOk = false;
bool otaUploadAttempted = false;
bool otaRebootScheduled = false;

unsigned long otaRebootAt = 0;
unsigned long lastSerialPrint = 0;
const unsigned long serialPrintInterval = 2000; // Stampa ogni 2 secondi

size_t otaBytesReceived = 0;
size_t otaExpectedBytes = 0;
int otaLastProgressPercent = -1;
String otaLastStatus = "OTA sempre attiva.";

// ===================== UTILITIES & WATCHDOG =====================

void feedWatchdog() {
  esp_task_wdt_reset();
}

void initTaskWatchdog() {
  esp_err_t status = esp_task_wdt_status(NULL);
  if (status == ESP_OK) return;

  if (status == ESP_ERR_NOT_FOUND) {
    esp_task_wdt_add(NULL);
    return;
  }

  if (status == ESP_ERR_INVALID_STATE) {
    esp_task_wdt_config_t wdtConfig = {
      .timeout_ms = 8000,
      .idle_core_mask = 0,
      .trigger_panic = true
    };
    esp_task_wdt_init(&wdtConfig);
    esp_task_wdt_add(NULL);
  }
}

// ===================== PAGINA WEB OTA =====================

String buildOtaPageHtml() {
  String html;
  html.reserve(1200);

  html += F("<!doctype html><html lang='it'><head><meta charset='utf-8'>");
  html += F("<meta name='viewport' content='width=device-width,initial-scale=1'>");
  html += F("<title>Master OTA</title><style>");
  html += F("body{font-family:Arial,sans-serif;max-width:600px;margin:20px auto;padding:20px;background:#f5f5f5;color:#202020;}");
  html += F(".card{background:#fff;border-radius:12px;padding:20px;box-shadow:0 3px 14px rgba(0,0,0,.08);margin-bottom:16px;}");
  html += F("code{background:#f0f0f0;padding:2px 6px;border-radius:6px;}input[type=file]{display:block;margin:12px 0;}button{padding:10px 16px;border:none;border-radius:8px;background:#005bbb;color:#fff;font-weight:700;cursor:pointer;}");
  html += F("</style></head><body>");
  html += F("<div class='card'><h1>Aggiornamento OTA Master</h1>");
  html += F("<p>SoftAP IP: <code>");
  html += WiFi.softAPIP().toString();
  html += F("</code></p><p>Stato: <strong>");
  html += otaLastStatus;
  html += F("</strong></p></div>");

  html += F("<div class='card'><h2>Carica Firmware (.bin)</h2>");
  html += F("<form method='POST' action='/update' enctype='multipart/form-data'>");
  html += F("<input type='file' name='update' accept='.bin' required>");
  html += F("<button type='submit'>Carica Firmware</button></form>");
  html += F("</div></body></html>");
  
  return html;
}

bool ensureOtaHttpAuth() {
  if (otaServer.authenticate(OTA_HTTP_USER, DIAG_TCP_PASSWORD)) {
    return true;
  }
  otaServer.requestAuthentication(BASIC_AUTH, "master-ota");
  return false;
}

void handleOtaRoot() {
  if (!ensureOtaHttpAuth()) return;
  otaServer.send(200, "text/html", buildOtaPageHtml());
}

void handleOtaUpdatePost() {
  if (!ensureOtaHttpAuth()) return;

  bool success = otaUploadAttempted && otaUpdateFinishedOk;
  otaServer.sendHeader("Connection", "close");

  if (success) {
    otaLastStatus = "OTA completata. Riavvio programmato.";
    otaServer.send(200, "text/plain", "Aggiornamento completato. Il master si riavvia.");
    otaRebootScheduled = true;
    otaRebootAt = millis() + 1500;
    Serial.println("OTA: aggiornamento completato. Riavvio in corso...");
  } else {
    otaLastStatus = "OTA fallita. Riprovare.";
    otaServer.send(500, "text/plain", "Aggiornamento fallito.");
    Serial.println("OTA: aggiornamento fallito.");
  }

  otaUpdateInProgress = false;
  otaUpdateSessionOpen = false;
  otaUploadAttempted = false;
  otaUpdateFinishedOk = false;
  otaLastProgressPercent = -1;
  otaBytesReceived = 0;
  otaExpectedBytes = 0;
}

void handleOtaUpdateUpload() {
  HTTPUpload& upload = otaServer.upload();

  if (upload.status == UPLOAD_FILE_START) {
    otaUpdateInProgress = true;
    otaRebootScheduled = false;
    otaUpdateSessionOpen = false;
    otaUploadAttempted = true;
    otaUpdateFinishedOk = false;
    otaBytesReceived = 0;
    otaExpectedBytes = upload.totalSize;
    otaLastProgressPercent = -1;
    otaLastStatus = "Upload OTA in corso...";

    Serial.println();
    Serial.println("OTA: Upload firmware avviato.");
    Serial.print("OTA: File = ");
    Serial.println(upload.filename);

    // Disabilita il task watchdog per tutta la durata dell'upload/scrittura flash:
    // handleClient() può restare bloccato a lungo durante la ricezione dei chunk
    // e la scrittura su flash, con rischio di reset a metà OTA.
    esp_task_wdt_delete(NULL);

    if (Update.begin(UPDATE_SIZE_UNKNOWN)) {
      otaUpdateSessionOpen = true;
    } else {
      otaLastStatus = "Errore inizializzazione OTA.";
      Update.printError(Serial);
    }
    return;
  }

  if (upload.status == UPLOAD_FILE_WRITE) {
    if (!otaUpdateSessionOpen) return;

    size_t written = Update.write(upload.buf, upload.currentSize);
    if (written != upload.currentSize) {
      otaLastStatus = "Errore scrittura OTA.";
      Update.printError(Serial);
      return;
    }

    otaBytesReceived += upload.currentSize;
    if (otaExpectedBytes > 0) {
      int progress = (int)((otaBytesReceived * 100U) / otaExpectedBytes);
      if (progress != otaLastProgressPercent && (progress == 100 || progress / 10 != otaLastProgressPercent / 10)) {
        otaLastProgressPercent = progress;
        Serial.print("OTA: progresso ");
        Serial.print(progress);
        Serial.println('%');
      }
    }
    return;
  }

  if (upload.status == UPLOAD_FILE_END) {
    if (!otaUpdateSessionOpen) {
      otaUpdateInProgress = false;
      return;
    }

    if (Update.end(true)) {
      otaUpdateFinishedOk = true;
      otaLastStatus = "Upload OTA completato con successo.";
      Serial.print("OTA: Upload completato. Byte ricevuti: ");
      Serial.println(upload.totalSize);
    } else {
      otaUpdateFinishedOk = false;
      otaLastStatus = "Errore finalizzazione OTA.";
      Update.printError(Serial);
    }
    initTaskWatchdog(); // riattiva il watchdog: upload terminato (successo o errore)
    return;
  }

  if (upload.status == UPLOAD_FILE_ABORTED) {
    otaUpdateInProgress = false;
    otaUpdateSessionOpen = false;
    otaUpdateFinishedOk = false;
    otaLastStatus = "Upload OTA interrotto.";
    Update.abort();
    Serial.println("OTA: Upload interrotto.");
    initTaskWatchdog(); // riattiva il watchdog anche in caso di interruzione
  }
}
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

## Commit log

2026-08-03 AGGIUNTO SCHEMI
    [PIR_MASTER_ESP32C3DISPLAY047.kicad_pcb, PIR_MASTER_ESP32C3DISPLAY047.kicad_sch, PIR_SLAVE_8266.kicad_pcb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]
2026-08-03 fw upd
    [partitions.csv]
